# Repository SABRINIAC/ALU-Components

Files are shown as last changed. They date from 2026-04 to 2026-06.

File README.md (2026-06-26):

# ALU Modules

| What it is

This project is the collection of PCB that make up all of the Intel 8080 (Which is what my CPU is based on) ALU's functionality. \
It contains modules for an 8 bit adder, subtractor, AND, OR, XOR, rotate left, and rotate right. Also it has a NOT module for the CMA instruction, which inverts all the bits in the accumulator register. \
Also coincidentally there are 8 modules, which will make multiplexing to choose data lines really nice and easy! If I ever decide to create the module for DAA, which I don't have atm because im kinda lazy and I think it'll be seldom used, I can alway make the NOT module not on the multiplex because it is exclusively used to invert the accumulator register for CMA and nothing else.

| Why I made it

Most of my reasoning can be found in the [RAM Module readme](https://github.com/SABRINIAC/DelayLineRAM-ShiftRegister) but aside from that I made this so I can do what CPUs are really good for. Math! These modules alone, making up the ALU, accounts for 96 out of the 255 instructions my CPU needs. Over a third at 37.6%! \
I don't think another project will get even close to implementing that many instructions! They would need a combination of making registers, and routing on the motherboard; which tbf the ALU also needs that. \

Also, making a computer out of pure transistors sounds really cool! Getting to learn how to make logic gates with them was fun, but I don't think I've fully committed how they precisely work to my brain yet... maybe later on in this project.

| Pictures

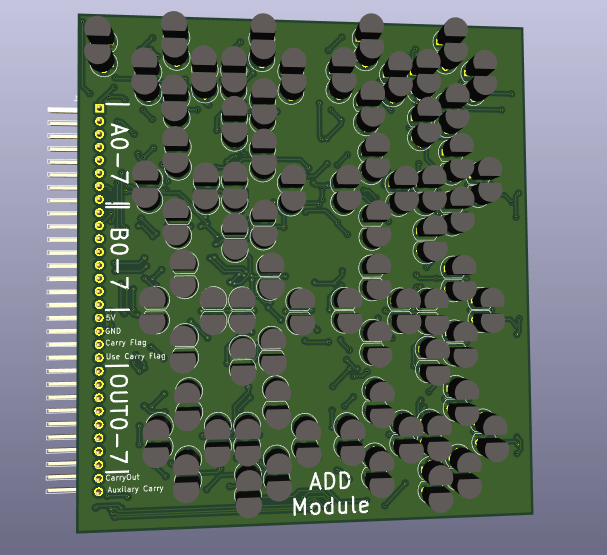
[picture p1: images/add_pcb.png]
Adder


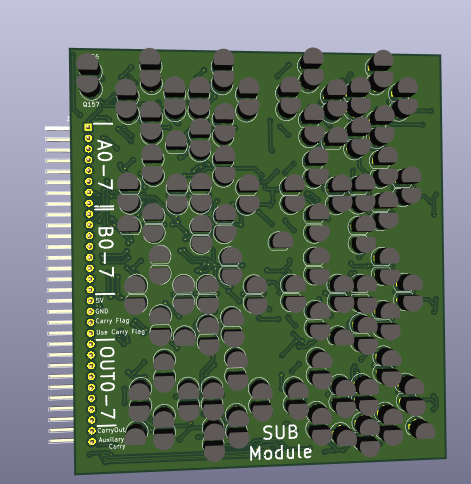
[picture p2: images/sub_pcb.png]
Subtractor


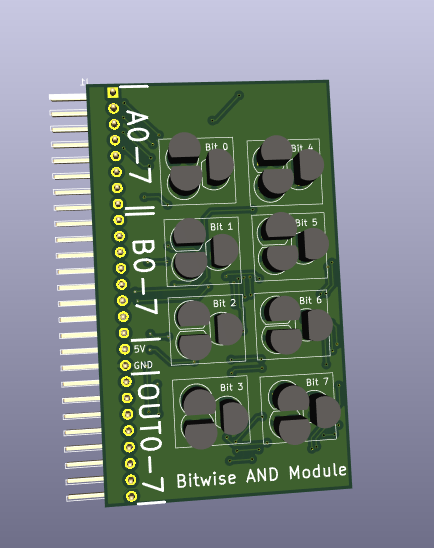
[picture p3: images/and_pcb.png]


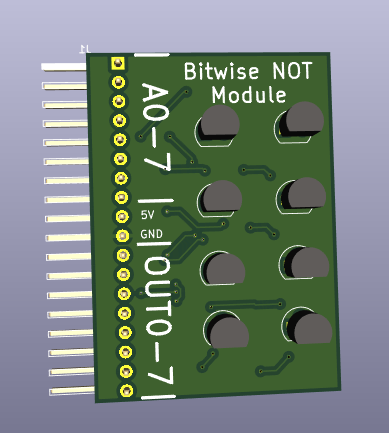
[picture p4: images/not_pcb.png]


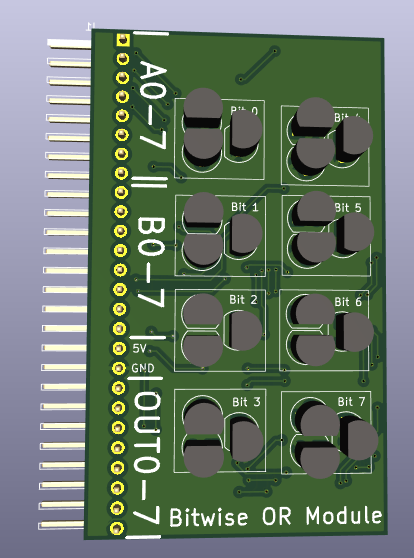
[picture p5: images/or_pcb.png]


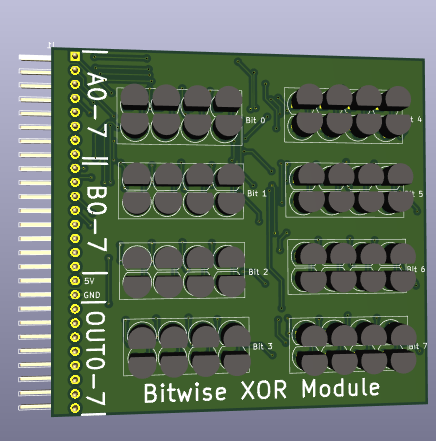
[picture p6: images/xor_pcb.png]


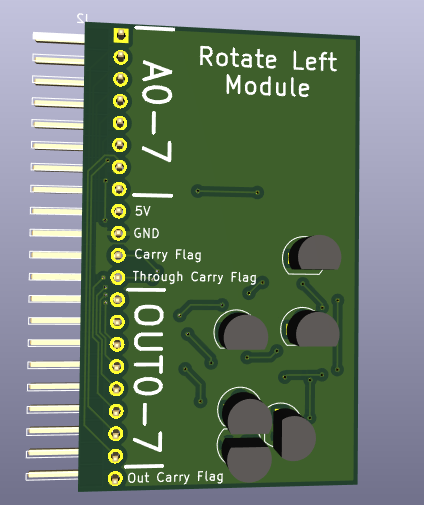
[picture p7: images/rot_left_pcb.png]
Rot. Left


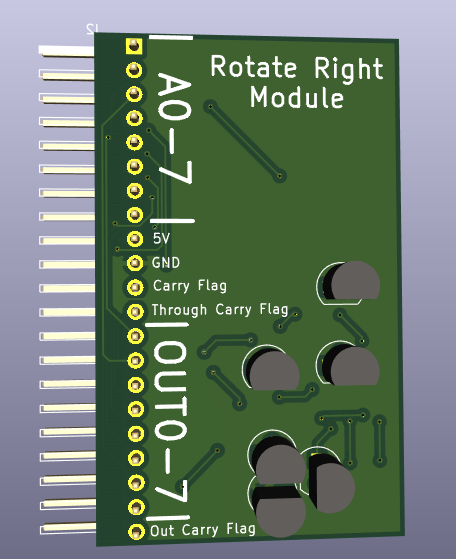
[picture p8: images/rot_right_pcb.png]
Rot. Right


| BOM + Quantity

You can see a greater breakdown in BOM.md, but here the table breakdown
| Part Name | Count |
|---|---|
| 1x2 Male Pin Headers | 99 |
| 2N2222 NPN Transistors | 432 |
| 1kΩ Resistor 0603 SMD | 670 |
| Adder PCB | 1 |
| Subtractor PCB | 1 |
| AND PCB | 1 |
| XOR PCB | 1 |
| OR PCB | 1 |
| NOT PCB | 1 |
| Rotate Right PCB | 1 |
| Rotate Left PCB | 1 |

# Built Modules
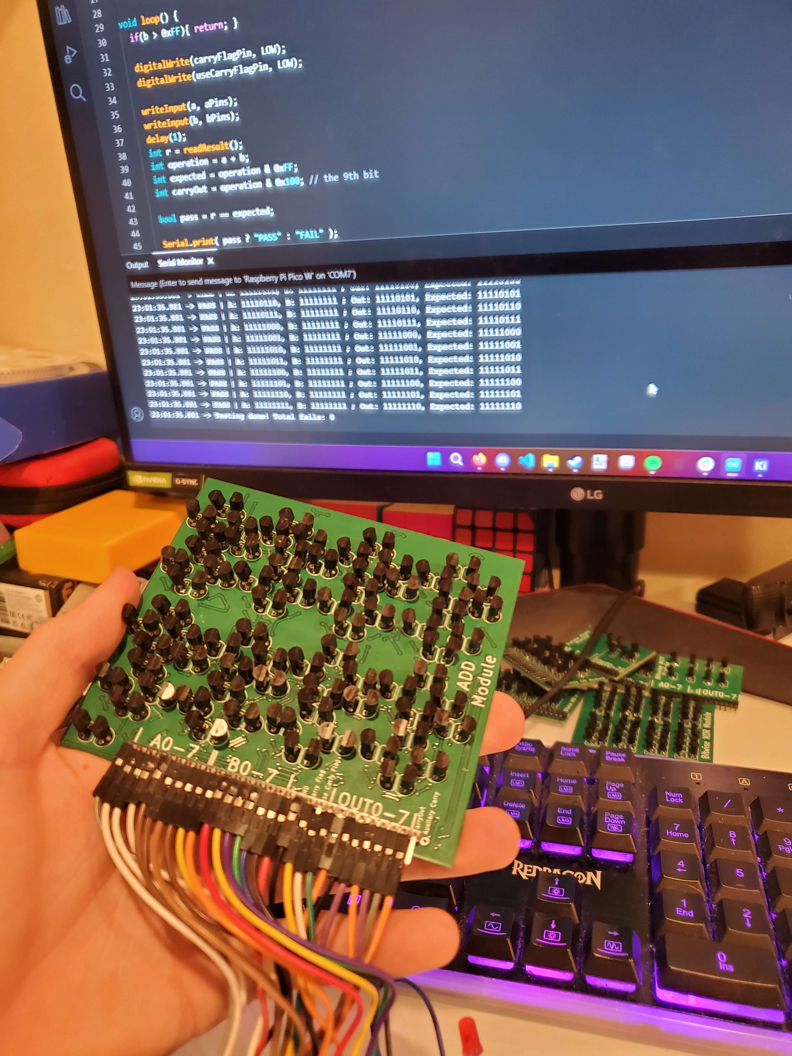
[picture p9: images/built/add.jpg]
Add

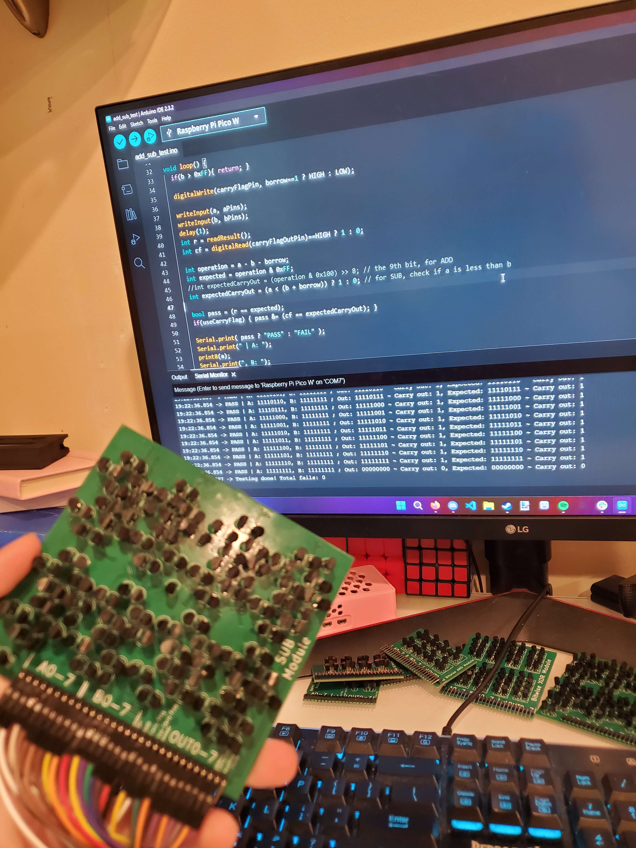
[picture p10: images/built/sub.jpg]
Sub

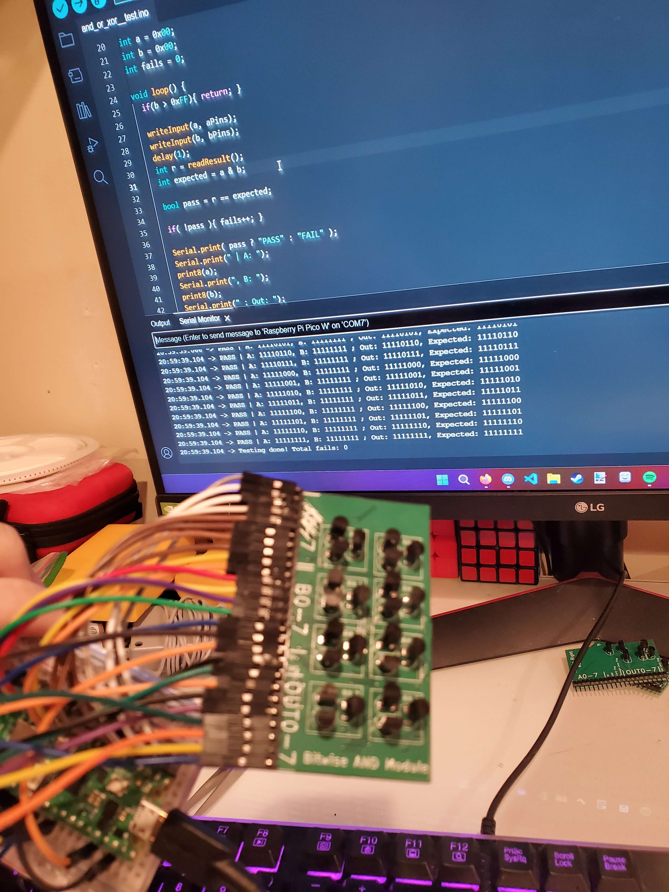
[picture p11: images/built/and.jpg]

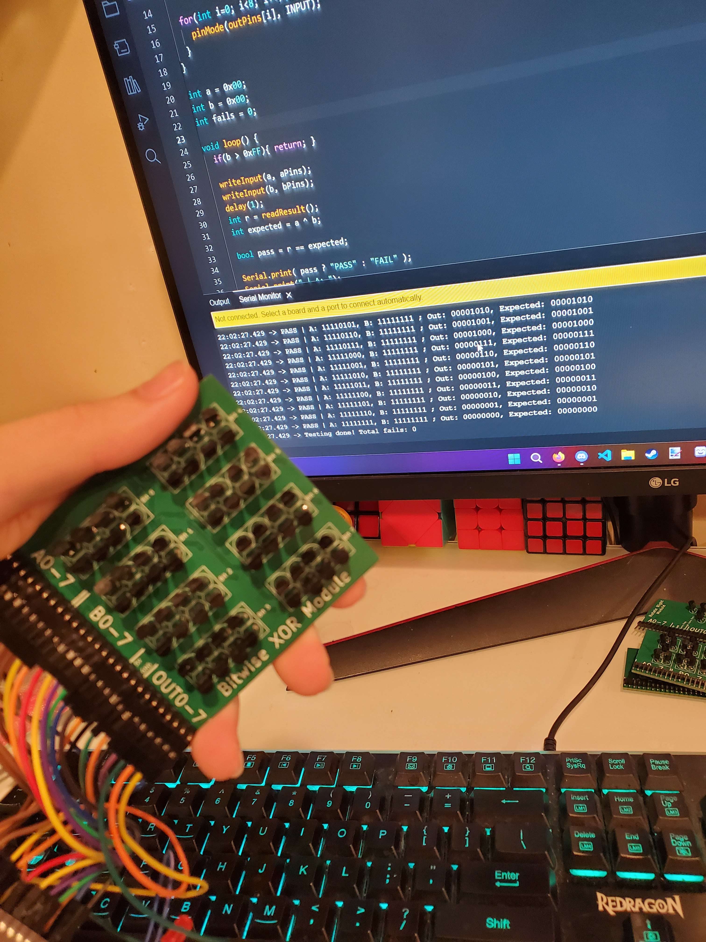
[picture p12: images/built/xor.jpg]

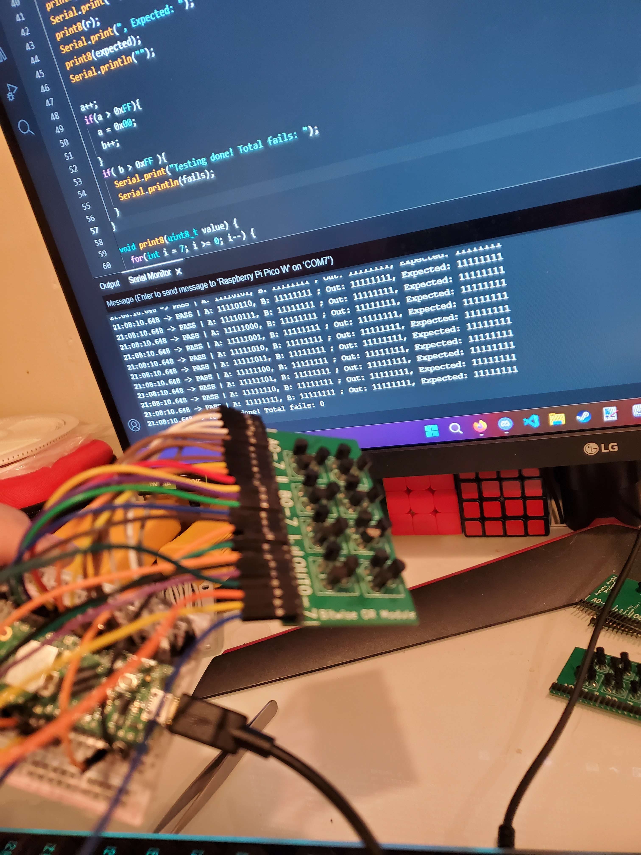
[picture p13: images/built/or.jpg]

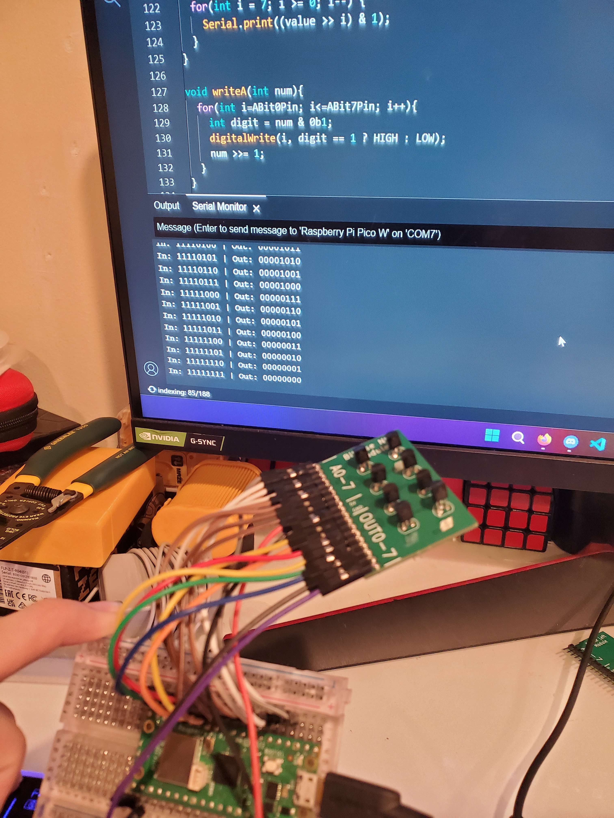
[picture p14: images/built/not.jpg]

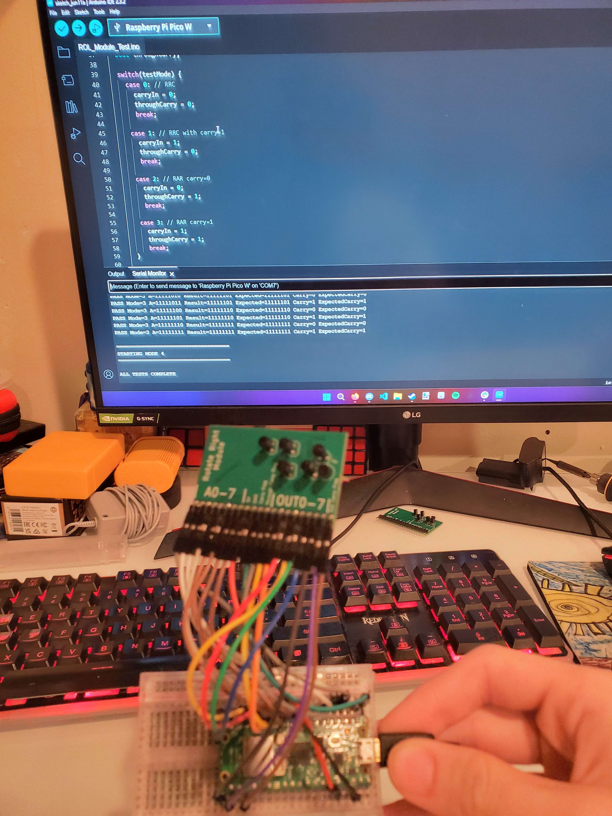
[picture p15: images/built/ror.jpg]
ROR

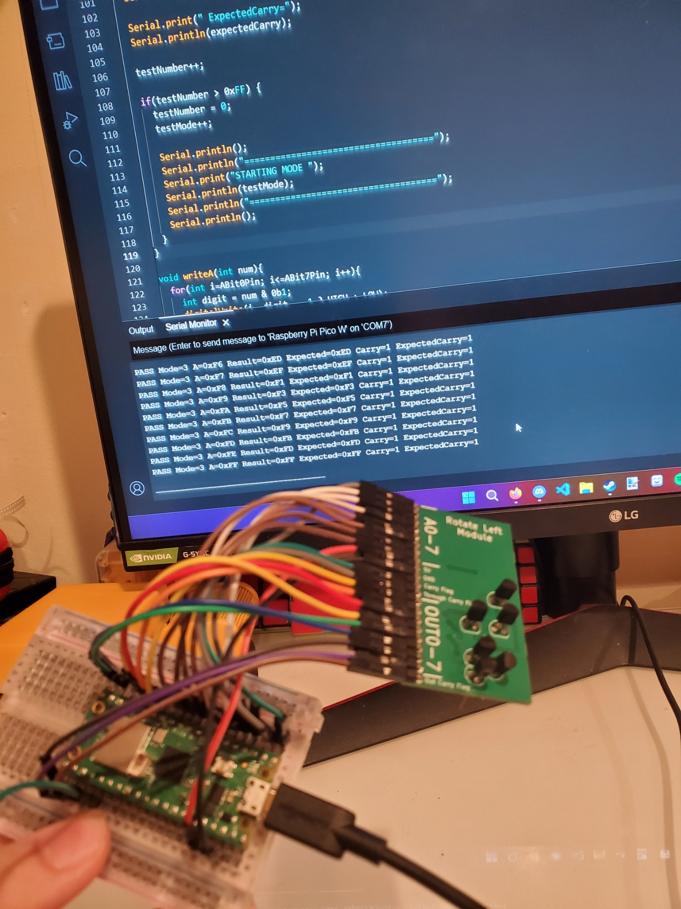
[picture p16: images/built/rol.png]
ROL


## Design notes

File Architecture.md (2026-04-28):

| What operations there are and their function
[Instruction Descriptions On Wikipedia](https://en.wikipedia.org/wiki/Intel_8080#Instruction_set) \

INR: Increment Register \
DCR: Decrement Register \
RLC: Accumulator << 1 ; Both the LSB and the Carry flag become old MSB \
RAL: Accumulator << 1 ; Carry flag becomes the old MSB ; LSB becomes the old Carry flag \
DAA: \
STC: Sets the carry flag to `1` | Don't include in the ALU? We can just modify the flag register? \
RRC: Accumulator >> 1 ; Both the MSB and Carry flag become the old LSB \
RAR: Accumulator >> 1 ; Carry flag becomes the old LSB ; MSB becomes the old carry flag \
CMA: Bitwise NOT on the current Accumulator ; Accumulator = !Accumulator \
CMC: Invert the carry flag | Don't include in the ALU? We can just modify the flag register? \
ADD + ADI: Add argument to the accumulator \
ADC + ACI: Add argument plus the carry flag to the accumulator \
SUB + SUI: Subtract the argument from the accumulator \
SBB + SBI: Subtract the argument and the carry flag from the accumulator \
ANA + ANI: Bitwise AND the argument with the accumulator \
XRA + XRI: Bitwise XOR the argument with the accumulator \
ORA + ORI: Bitwise OR the argument with the accumulator \
CMP + CPI: Accumulator minus the argument, but only changes flags \

| Circuits Needed

DAA: \
STC: Sets the carry flag to `1` | Don't include in the ALU? We can just modify the flag register? \
CMC: Invert the carry flag | Don't include in the ALU? We can just modify the flag register? \

~Adder; For INR, ADD, ADI, ADC, and ACI~ \
~Subtractor; For DCR, SUB, SUI, SBB, SBI, CMP, and CPI~ \
~Bitwise AND; For ANA, and ANI~ \
~Bitwise XOR; For XRA, and XRI~ \
~Bitwise OR; For ORA, and ORI~ \
~Bitwise NOT; For CMA~ \
~Rotate Right; For RRC, and RAR~ \
~Rotate Left; for RLC, and RAL~ \

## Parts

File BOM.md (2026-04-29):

Adder
- 1x Adder PCB
- 1x30 Male Pin Header
- 146 NPN Transistors
- 219 1kΩ Resistor 0603 SMD

Subtractor
- 1x Subtractor PCB
- 1x30 Male Pin Header
- 155 NPN Transistors
- 237 1kΩ Resistor 0603 SMD

Bitwise AND
- 1x AND PCB
- 1x26 Male Pin Header
- 23 NPN Transistors
- 40 1kΩ Resistor 0603 SMD

Bitwise XOR
- 1x XOR PCB
- 1x26 Male Pin Header
- 64 NPN Transistors
- 96 1kΩ Resistor 0603 SMD

Bitwise OR
- 1x OR PCB
- 1x26 Male Pin Header
- 24 NPN Transistors
- 40 1kΩ Resistor 0603 SMD

Bitwise NOT
- 1x NOT PCB
- 1x18 Male Pin Header
- 8 NPN Transistors
- 16 1kΩ Resistor 0603 SMD

Rotate Right
- 1x Rotate Right PCB
- 1x21 Male Pin Header
- 6 NPN Transistors
- 11 1kΩ Resistor 0603 SMD

Rotate Left
- 1x Rotate Left PCB
- 1x21 Male Pin Header
- 6 NPN Transistors
- 11 1kΩ Resistor 0603 SMD

**Total**:
- 99 1x2 Male Pin Header
- 432 NPN Transistors
- 670 1kΩ Resistor 0603 SMD
- 1x Adder PCB
- 1x Subtractor PCB
- 1x AND PCB
- 1x XOR PCB
- 1x OR PCB
- 1x NOT PCB
- 1x Rotate Right PCB
- 1x Rotate Left PCB

**PCBs** \
From JLCPCB
- $2 for the first PCB, then $4 per PCB after that -> $30
- Shipping: $3.30 fro the first, ~$1.30 to add 1 more PCB to that same shipment -> 3.30 + 7 * (1.30) = $12.4
- Or just $15.09 for shipping if I order them at the same time

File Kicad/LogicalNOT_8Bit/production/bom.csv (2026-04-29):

Designator | Footprint | Quantity | Value | LCSC Part #
J1 | PinHeader_1x18_P2.54mm_Horizontal | 1 | Conn_01x18_Pin
Q1, Q2, Q3, Q4, Q5, Q6, Q7, Q8 | TO-92 | 8 | NPN
R1, R10, R11, R12, R13, R14, R15, R16, R2, R3, R4, R5, R6, R7, R8, R9 | 0603 | 16 | 1kΩ

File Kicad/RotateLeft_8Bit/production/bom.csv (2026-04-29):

Designator | Footprint | Quantity | Value | LCSC Part #
J2 | PinHeader_1x21_P2.54mm_Horizontal | 1 | Conn_01x21_Pin
Q1, Q2, Q3, Q4, Q5, Q6 | TO-92 | 6 | NPN
R1, R10, R11, R2, R3, R4, R5, R6, R7, R8, R9 | 0603 | 11 | 1kΩ

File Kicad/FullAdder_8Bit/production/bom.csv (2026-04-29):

Designator | Footprint | Quantity | Value | LCSC Part #
J1 | PinHeader_1x30_P2.54mm_Horizontal | 1 | Conn_01x30_Pin
Q10, Q100, Q101, Q102, Q103, Q104, Q105, Q106, Q107, Q108, Q109, Q11, Q110, Q111, Q112, Q113, Q114, Q115, Q116, Q117, Q118, Q119, Q12, Q120, Q121, Q122, Q123, Q124, Q125, Q126, Q127, Q128, Q129, Q13, Q130, Q131, Q132, Q133, Q134, Q135, Q136, Q137, Q138, Q139, Q14, Q140, Q141, Q142, Q143, Q144, Q145, Q146, Q147, Q148, Q15, Q16, Q17, Q18, Q19, Q20, Q21, Q22, Q23, Q24, Q25, Q26, Q27, Q28, Q29, Q3, Q30, Q31, Q32, Q33, Q34, Q35, Q36, Q37, Q38, Q39, Q4, Q40, Q41, Q42, Q43, Q44, Q45, Q46, Q47, Q48, Q49, Q5, Q50, Q51, Q52, Q53, Q54, Q55, Q56, Q57, Q58, Q59, Q6, Q60, Q61, Q62, Q63, Q64, Q65, Q66, Q67, Q68, Q69, Q7, Q70, Q71, Q72, Q73, Q74, Q75, Q76, Q77, Q78, Q79, Q8, Q80, Q81, Q82, Q83, Q84, Q85, Q86, Q87, Q88, Q89, Q9, Q90, Q91, Q92, Q93, Q94, Q95, Q96, Q97, Q98, Q99 | TO-92 | 146 | NPN
R10, R100, R101, R102, R103, R104, R105, R106, R107, R108, R109, R11, R110, R111, R112, R113, R114, R115, R116, R117, R118, R119, R12, R120, R121, R122, R123, R124, R125, R126, R127, R128, R129, R13, R130, R131, R132, R133, R134, R135, R136, R137, R138, R139, R14, R140, R141, R142, R143, R144, R145, R146, R147, R148, R149, R15, R150, R151, R152, R153, R154, R155, R156, R157, R158, R159, R16, R160, R161, R162, R163, R164, R165, R166, R167, R168, R169, R17, R170, R171, R172, R173, R174, R175, R176, R177, R178, R179, R18, R180, R181, R182, R183, R184, R185, R186, R187, R188, R189, R19, R190, R191, R192, R193, R194, R195, R196, R197, R198, R199, R20, R200, R201, R202, R203, R204, R205, R206, R207, R208, R209, R21, R210, R211, R212, R213, R214, R215, R216, R217, R218, R219, R22, R220, R221, R222, R23, R24, R25, R26, R27, R28, R29, R30, R31, R32, R33, R34, R35, R36, R37, R38, R39, R4, R40, R41, R42, R43, R44, R45, R46, R47, R48, R49, R5, R50, R51, R52, R53, R54, R55, R56, R57, R58, R59, R6, R60, R61, R62, R63, R64, R65, R66, R67, R68, R69, R7, R70, R71, R72, R73, R74, R75, R76, R77, R78, R79, R8, R80, R81 | 0603 | 200 | 1kΩ
R82, R83, R84, R85, R86, R87, R88, R89, R9, R90, R91, R92, R93, R94, R95, R96, R97, R98, R99 | 0603 | 19 | 1kΩ

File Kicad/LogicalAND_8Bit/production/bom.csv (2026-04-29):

Designator | Footprint | Quantity | Value | LCSC Part #
J1 | PinHeader_1x26_P2.54mm_Horizontal | 1 | Conn_01x26_Pin
Q1, Q10, Q11, Q12, Q13, Q14, Q15, Q16, Q17, Q18, Q19, Q2, Q20, Q21, Q22, Q23, Q24, Q3, Q4, Q5, Q6, Q7, Q8, Q9 | TO-92 | 24 | NPN
R1, R10, R11, R12, R13, R14, R15, R16, R17, R18, R19, R2, R20, R21, R22, R23, R24, R25, R26, R27, R28, R29, R3, R30, R31, R32, R33, R34, R35, R36, R37, R38, R39, R4, R40, R5, R6, R7, R8, R9 | 0603 | 40 | 1kΩ

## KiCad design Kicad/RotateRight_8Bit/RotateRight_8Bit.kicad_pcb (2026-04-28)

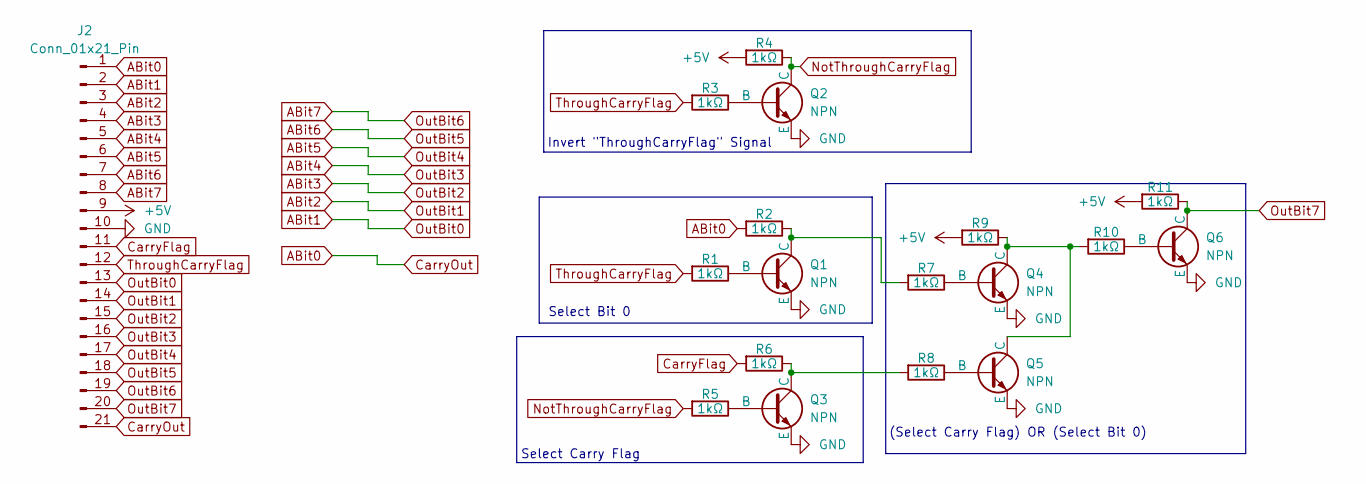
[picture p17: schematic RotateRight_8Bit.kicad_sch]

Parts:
J2: Conn_01x21_Pin; PinHeader_1x21_P2.54mm_Horizontal
Q1, Q2, Q3, Q4, Q5, Q6: NPN; TO-92
R1, R2, R3, R4, R5, R6, R7, R8, R9, R10, R11: 1kΩ; R_0603_1608Metric

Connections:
+5V: J2.9, R4.2, R9.2, R11.2
ABit0: J2.1, J2.21, R2.2
ABit1: J2.2, J2.13
ABit2: J2.3, J2.14
ABit3: J2.4, J2.15
ABit4: J2.5, J2.16
ABit5: J2.6, J2.17
ABit6: J2.7, J2.18
ABit7: J2.8, J2.19
CarryFlag: J2.11, R6.2
GND: J2.10, Q1.3 (E), Q2.3 (E), Q3.3 (E), Q4.3 (E), Q5.3 (E), Q6.3 (E)
unnamed: Q1.2 (B), R1.1
unnamed: Q1.1 (C), R2.1, R7.2
unnamed: Q2.2 (B), R3.1
unnamed: Q3.2 (B), R5.1
unnamed: Q3.1 (C), R6.1, R8.2
unnamed: Q4.2 (B), R7.1
unnamed: Q4.1 (C), Q5.1 (C), R9.1, R10.2
unnamed: Q5.2 (B), R8.1
unnamed: Q6.2 (B), R10.1
NotThroughCarryFlag: Q2.1 (C), R4.1, R5.2
OutBit7: J2.20, Q6.1 (C), R11.1
ThroughCarryFlag: J2.12, R1.2, R3.2

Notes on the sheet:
(Select Carry Flag) OR (Select Bit 0)
Select Bit 0
Select Carry Flag
Invert "ThroughCarryFlag" Signal

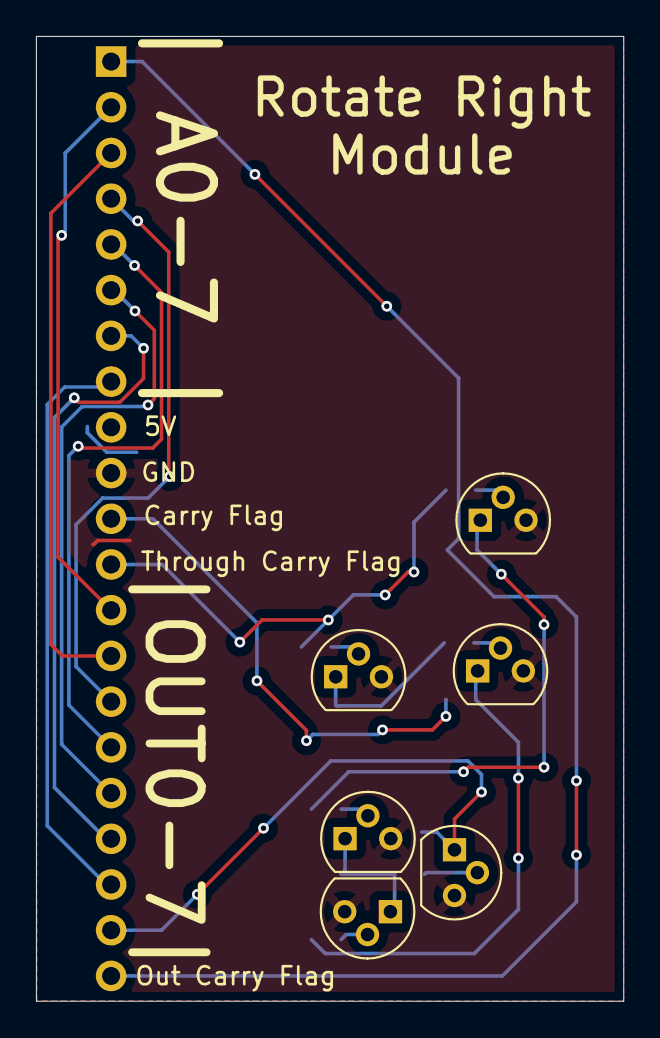
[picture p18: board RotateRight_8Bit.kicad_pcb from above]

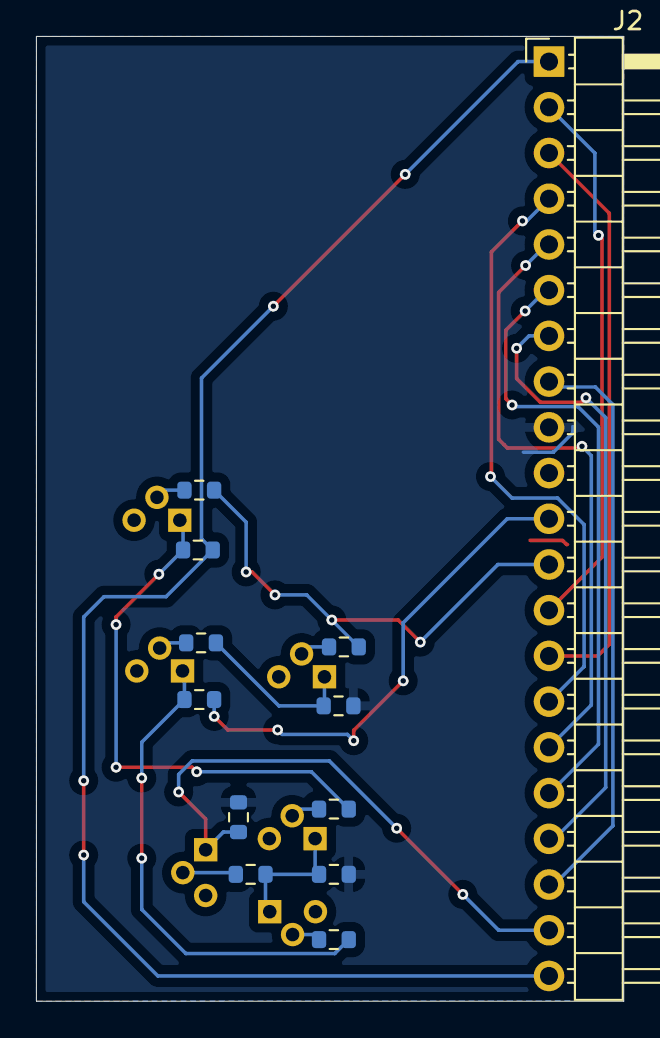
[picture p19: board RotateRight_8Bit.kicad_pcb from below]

Board: 2 copper layers, 32.6 x 53.6 mm, 18 parts (12 on the bottom side), 23 nets.

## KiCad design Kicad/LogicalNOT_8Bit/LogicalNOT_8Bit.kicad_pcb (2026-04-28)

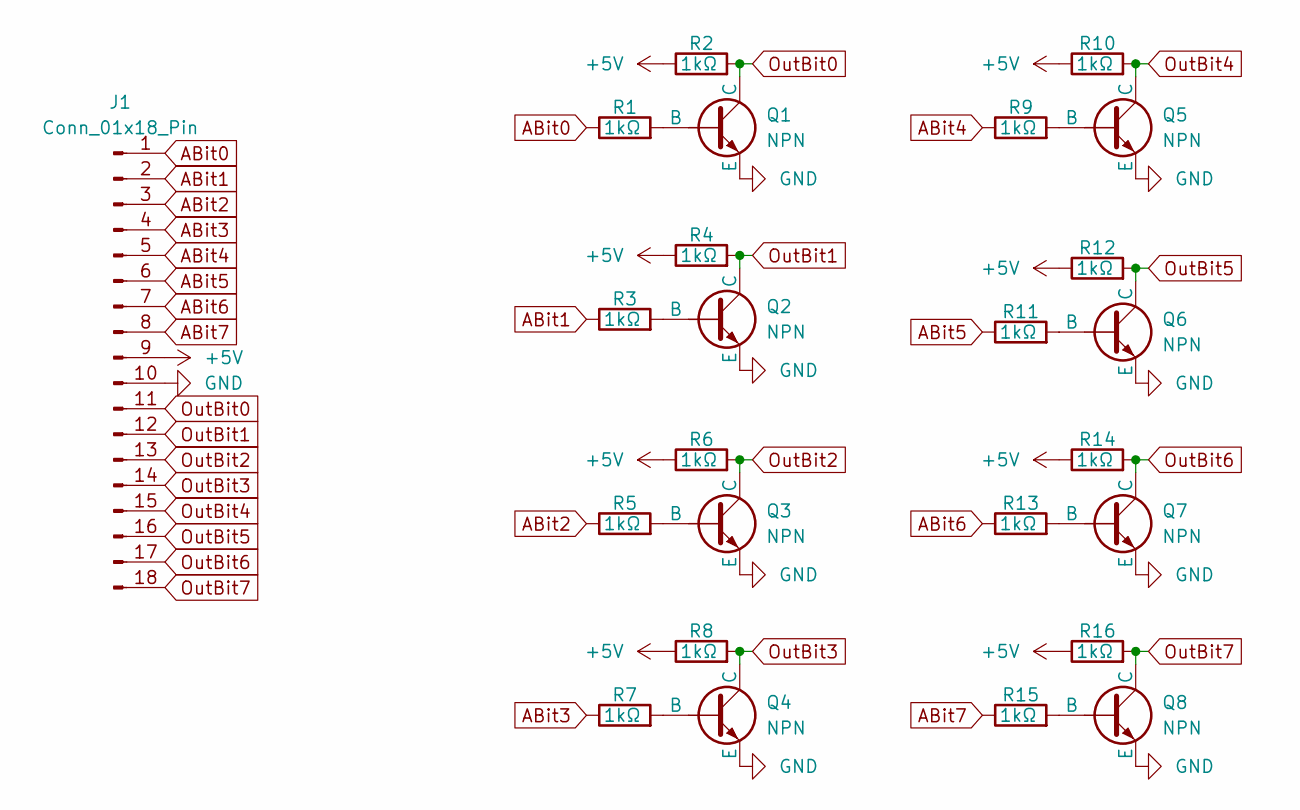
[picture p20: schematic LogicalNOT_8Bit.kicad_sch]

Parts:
J1: Conn_01x18_Pin; PinHeader_1x18_P2.54mm_Horizontal
Q1, Q2, Q3, Q4, Q5, Q6, Q7, Q8: NPN; TO-92
R1, R2, R3, R4, R5, R6, R7, R8, R9, R10, R11, R12, R13, R14, R15, R16: 1kΩ; R_0603_1608Metric

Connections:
+5V: J1.9, R2.1, R4.1, R6.1, R8.1, R10.1, R12.1, R14.1, R16.1
ABit0: J1.1, R1.1
ABit1: J1.2, R3.1
ABit2: J1.3, R5.1
ABit3: J1.4, R7.1
ABit4: J1.5, R9.1
ABit5: J1.6, R11.1
ABit6: J1.7, R13.1
ABit7: J1.8, R15.1
GND: J1.10, Q1.3 (E), Q2.3 (E), Q3.3 (E), Q4.3 (E), Q5.3 (E), Q6.3 (E), Q7.3 (E), Q8.3 (E)
unnamed: Q1.2 (B), R1.2
unnamed: Q2.2 (B), R3.2
unnamed: Q3.2 (B), R5.2
unnamed: Q4.2 (B), R7.2
unnamed: Q5.2 (B), R9.2
unnamed: Q6.2 (B), R11.2
unnamed: Q7.2 (B), R13.2
unnamed: Q8.2 (B), R15.2
OutBit0: J1.11, Q1.1 (C), R2.2
OutBit1: J1.12, Q2.1 (C), R4.2
OutBit2: J1.13, Q3.1 (C), R6.2
OutBit3: J1.14, Q4.1 (C), R8.2
OutBit4: J1.15, Q5.1 (C), R10.2
OutBit5: J1.16, Q6.1 (C), R12.2
OutBit6: J1.17, Q7.1 (C), R14.2
OutBit7: J1.18, Q8.1 (C), R16.2

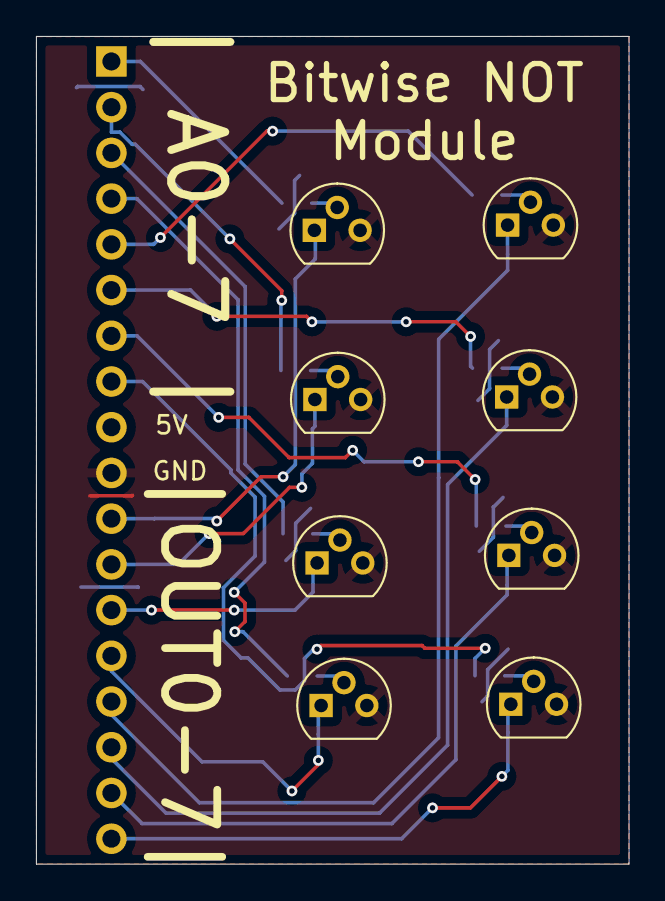
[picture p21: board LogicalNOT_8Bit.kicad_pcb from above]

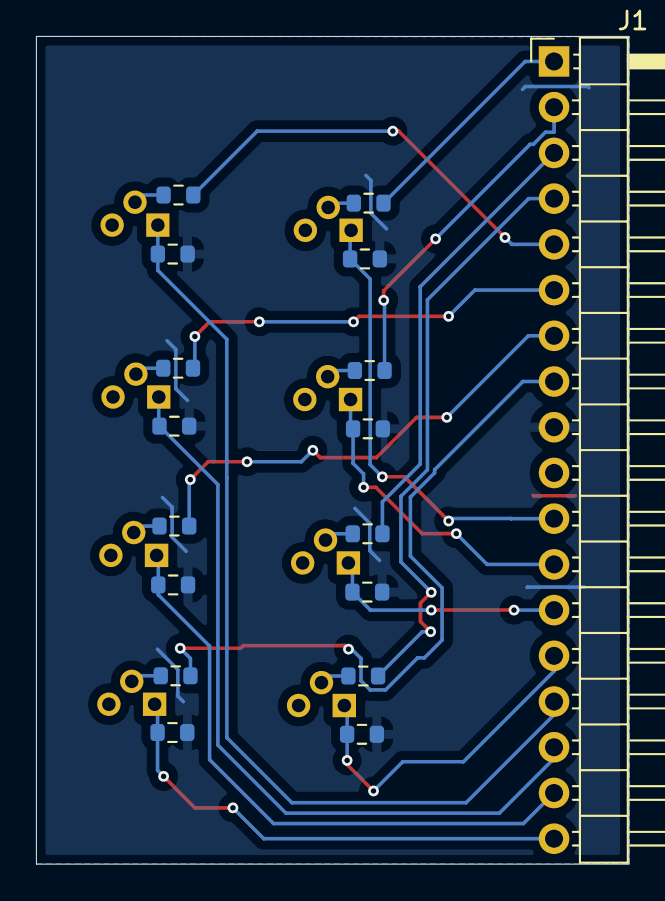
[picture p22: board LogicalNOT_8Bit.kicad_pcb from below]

Board: 2 copper layers, 32.9 x 46.0 mm, 25 parts (17 on the bottom side), 26 nets.

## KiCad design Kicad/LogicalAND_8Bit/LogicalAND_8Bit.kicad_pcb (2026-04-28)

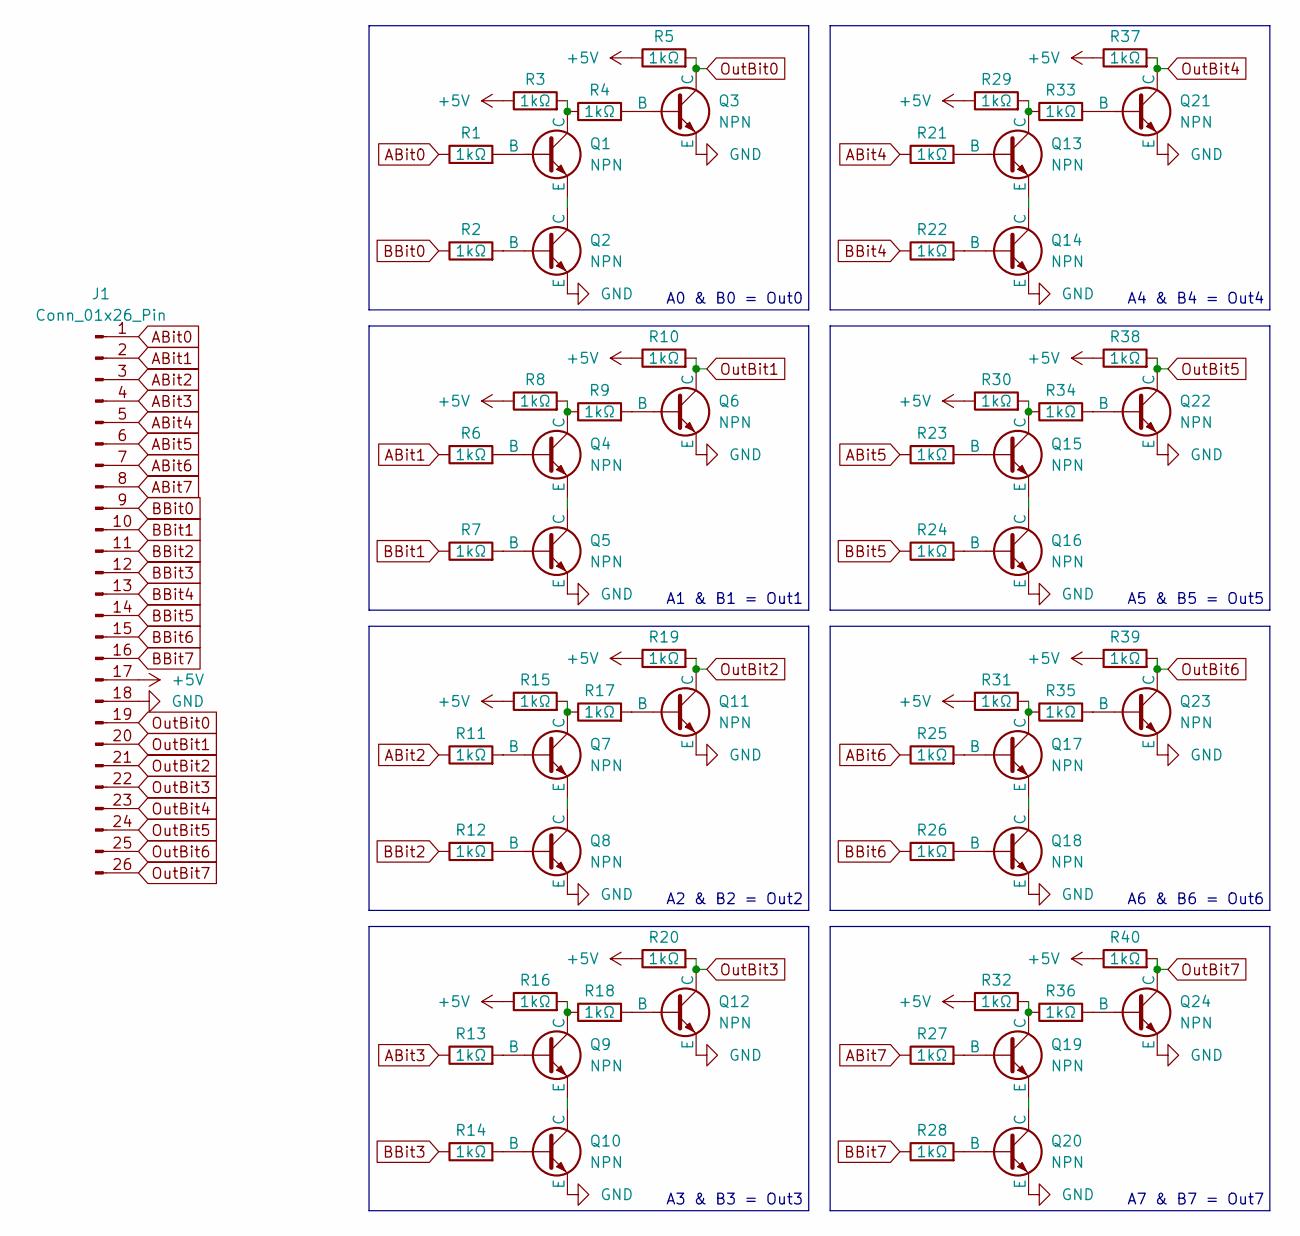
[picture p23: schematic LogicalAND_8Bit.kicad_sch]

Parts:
J1: Conn_01x26_Pin; PinHeader_1x26_P2.54mm_Horizontal
Q1, Q2, Q3, Q4, Q5, Q6, Q7, Q8, Q9, Q10, Q11, Q12, Q13, Q14, Q15, Q16, Q17, Q18, Q19, Q20, Q21, Q22, Q23, Q24: NPN; TO-92
R1, R2, R3, R4, R5, R6, R7, R8, R9, R10, R11, R12, R13, R14, R15, R16, R17, R18, R19, R20, R21, R22, R23, R24, R25, R26, R27, R28, R29, R30, R31, R32, R33, R34, R35, R36, R37, R38, R39, R40: 1kΩ; R_0603_1608Metric

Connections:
+5V: J1.17, R3.1, R5.1, R8.1, R10.1, R15.1, R16.1, R19.1, R20.1, R29.1, R30.1, R31.1, R32.1, R37.1, R38.1, R39.1, R40.1
ABit0: J1.1, R1.1
ABit1: J1.2, R6.1
ABit2: J1.3, R11.1
ABit3: J1.4, R13.1
ABit4: J1.5, R21.1
ABit5: J1.6, R23.1
ABit6: J1.7, R25.1
ABit7: J1.8, R27.1
BBit0: J1.9, R2.1
BBit1: J1.10, R7.1
BBit2: J1.11, R12.1
BBit3: J1.12, R14.1
BBit4: J1.13, R22.1
BBit5: J1.14, R24.1
BBit6: J1.15, R26.1
BBit7: J1.16, R28.1
GND: J1.18, Q2.3 (E), Q3.3 (E), Q5.3 (E), Q6.3 (E), Q8.3 (E), Q10.3 (E), Q11.3 (E), Q12.3 (E), Q14.3 (E), Q16.3 (E), Q18.3 (E), Q20.3 (E), Q21.3 (E), Q22.3 (E), Q23.3 (E), Q24.3 (E)
unnamed: Q1.2 (B), R1.2
unnamed: Q1.1 (C), R3.2, R4.1
unnamed: Q1.3 (E), Q2.1 (C)
unnamed: Q2.2 (B), R2.2
unnamed: Q3.2 (B), R4.2
unnamed: Q4.2 (B), R6.2
unnamed: Q4.1 (C), R8.2, R9.1
unnamed: Q4.3 (E), Q5.1 (C)
unnamed: Q5.2 (B), R7.2
unnamed: Q6.2 (B), R9.2
unnamed: Q7.2 (B), R11.2
unnamed: Q7.1 (C), R15.2, R17.1
unnamed: Q7.3 (E), Q8.1 (C)
unnamed: Q8.2 (B), R12.2
unnamed: Q9.2 (B), R13.2
unnamed: Q9.1 (C), R16.2, R18.1
unnamed: Q10.2 (B), R14.2
unnamed: Q9.3 (E), Q10.1 (C)
unnamed: Q11.2 (B), R17.2
unnamed: Q12.2 (B), R18.2
unnamed: Q13.2 (B), R21.2
unnamed: Q13.1 (C), R29.2, R33.1
unnamed: Q13.3 (E), Q14.1 (C)
unnamed: Q14.2 (B), R22.2
unnamed: Q15.2 (B), R23.2
unnamed: Q15.1 (C), R30.2, R34.1
unnamed: Q15.3 (E), Q16.1 (C)
unnamed: Q16.2 (B), R24.2
unnamed: Q17.2 (B), R25.2
unnamed: Q17.1 (C), R31.2, R35.1
unnamed: Q17.3 (E), Q18.1 (C)
unnamed: Q18.2 (B), R26.2
unnamed: Q19.2 (B), R27.2
unnamed: Q19.1 (C), R32.2, R36.1
unnamed: Q19.3 (E), Q20.1 (C)
unnamed: Q20.2 (B), R28.2
unnamed: Q21.2 (B), R33.2
unnamed: Q22.2 (B), R34.2
unnamed: Q23.2 (B), R35.2
unnamed: Q24.2 (B), R36.2
OutBit0: J1.19, Q3.1 (C), R5.2
OutBit1: J1.20, Q6.1 (C), R10.2
OutBit2: J1.21, Q11.1 (C), R19.2
OutBit3: J1.22, Q12.1 (C), R20.2
OutBit4: J1.23, Q21.1 (C), R37.2
OutBit5: J1.24, Q22.1 (C), R38.2
OutBit6: J1.25, Q23.1 (C), R39.2
OutBit7: J1.26, Q24.1 (C), R40.2

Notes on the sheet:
A7 & B7 = Out7
A4 & B4 = Out4
A6 & B6 = Out6
A0 & B0 = Out0
A3 & B3 = Out3
A2 & B2 = Out2
A1 & B1 = Out1
A5 & B5 = Out5

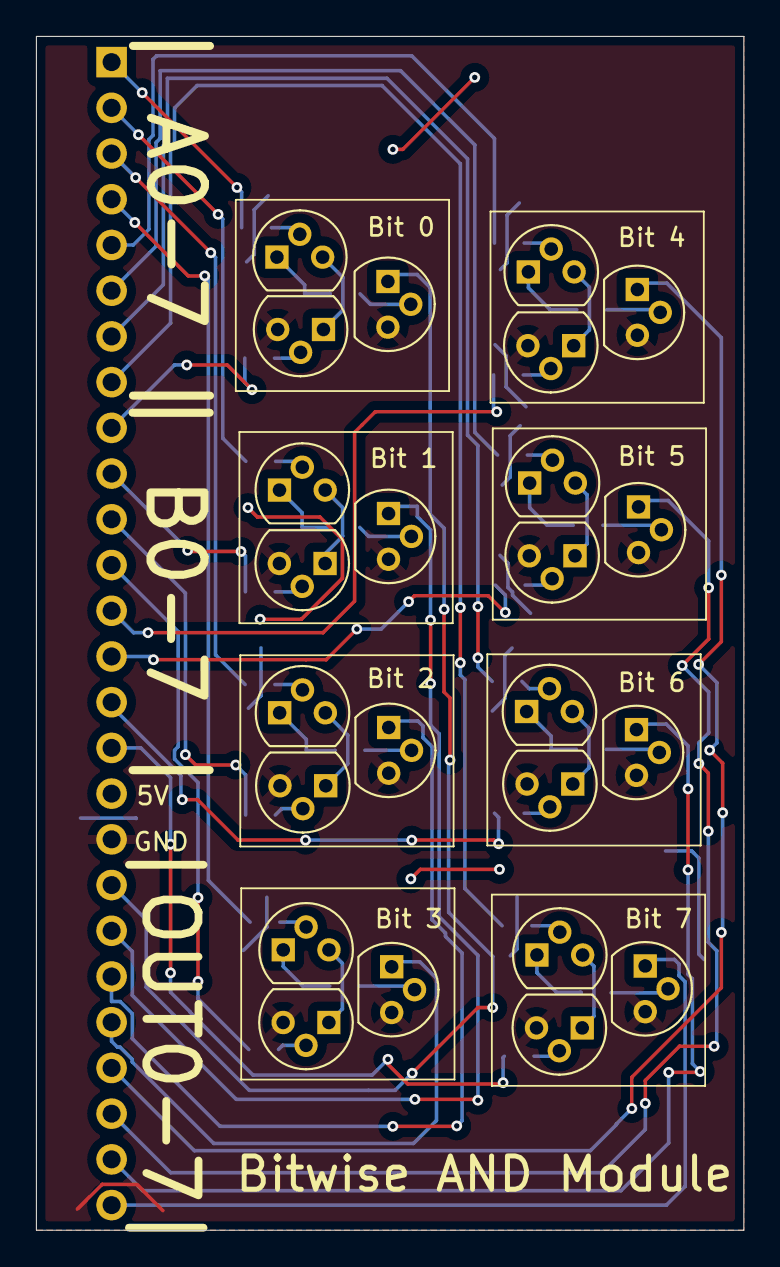
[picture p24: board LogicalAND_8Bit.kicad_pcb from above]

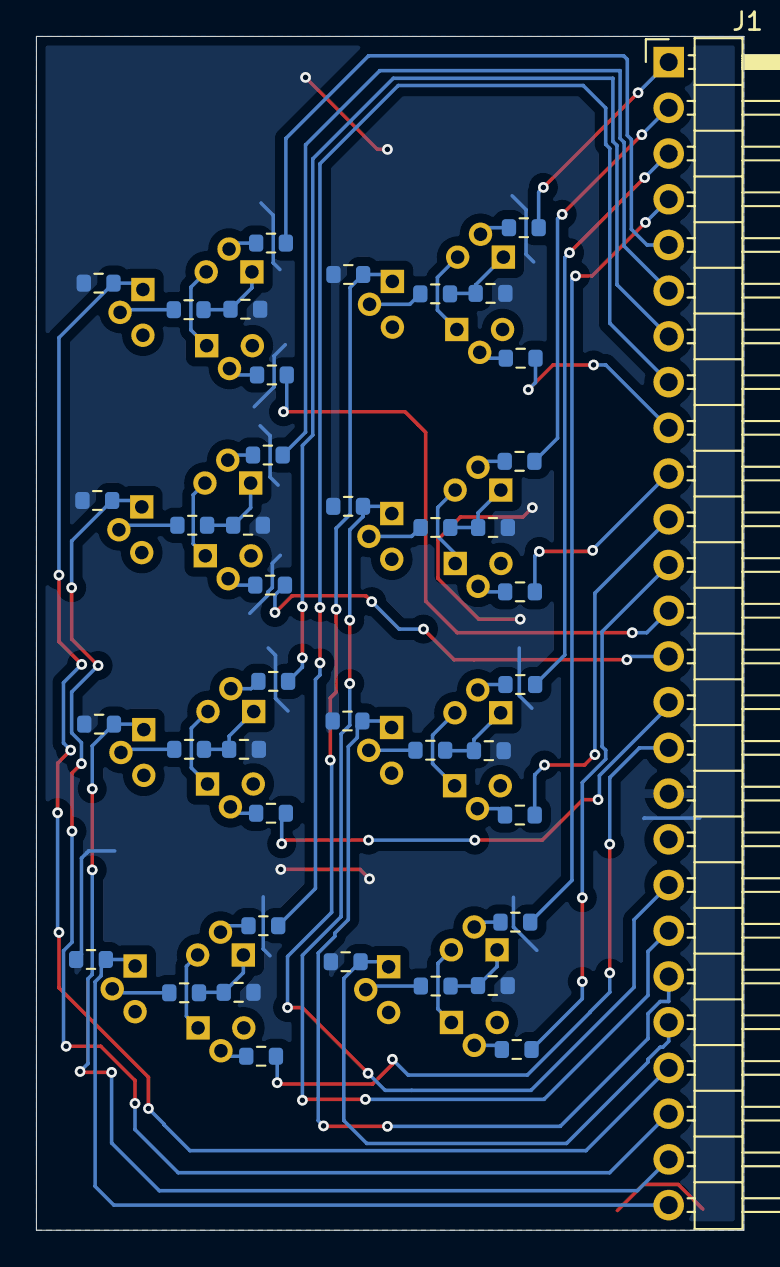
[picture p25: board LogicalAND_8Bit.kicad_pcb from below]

Board: 2 copper layers, 39.3 x 66.3 mm, 65 parts (41 on the bottom side), 66 nets.

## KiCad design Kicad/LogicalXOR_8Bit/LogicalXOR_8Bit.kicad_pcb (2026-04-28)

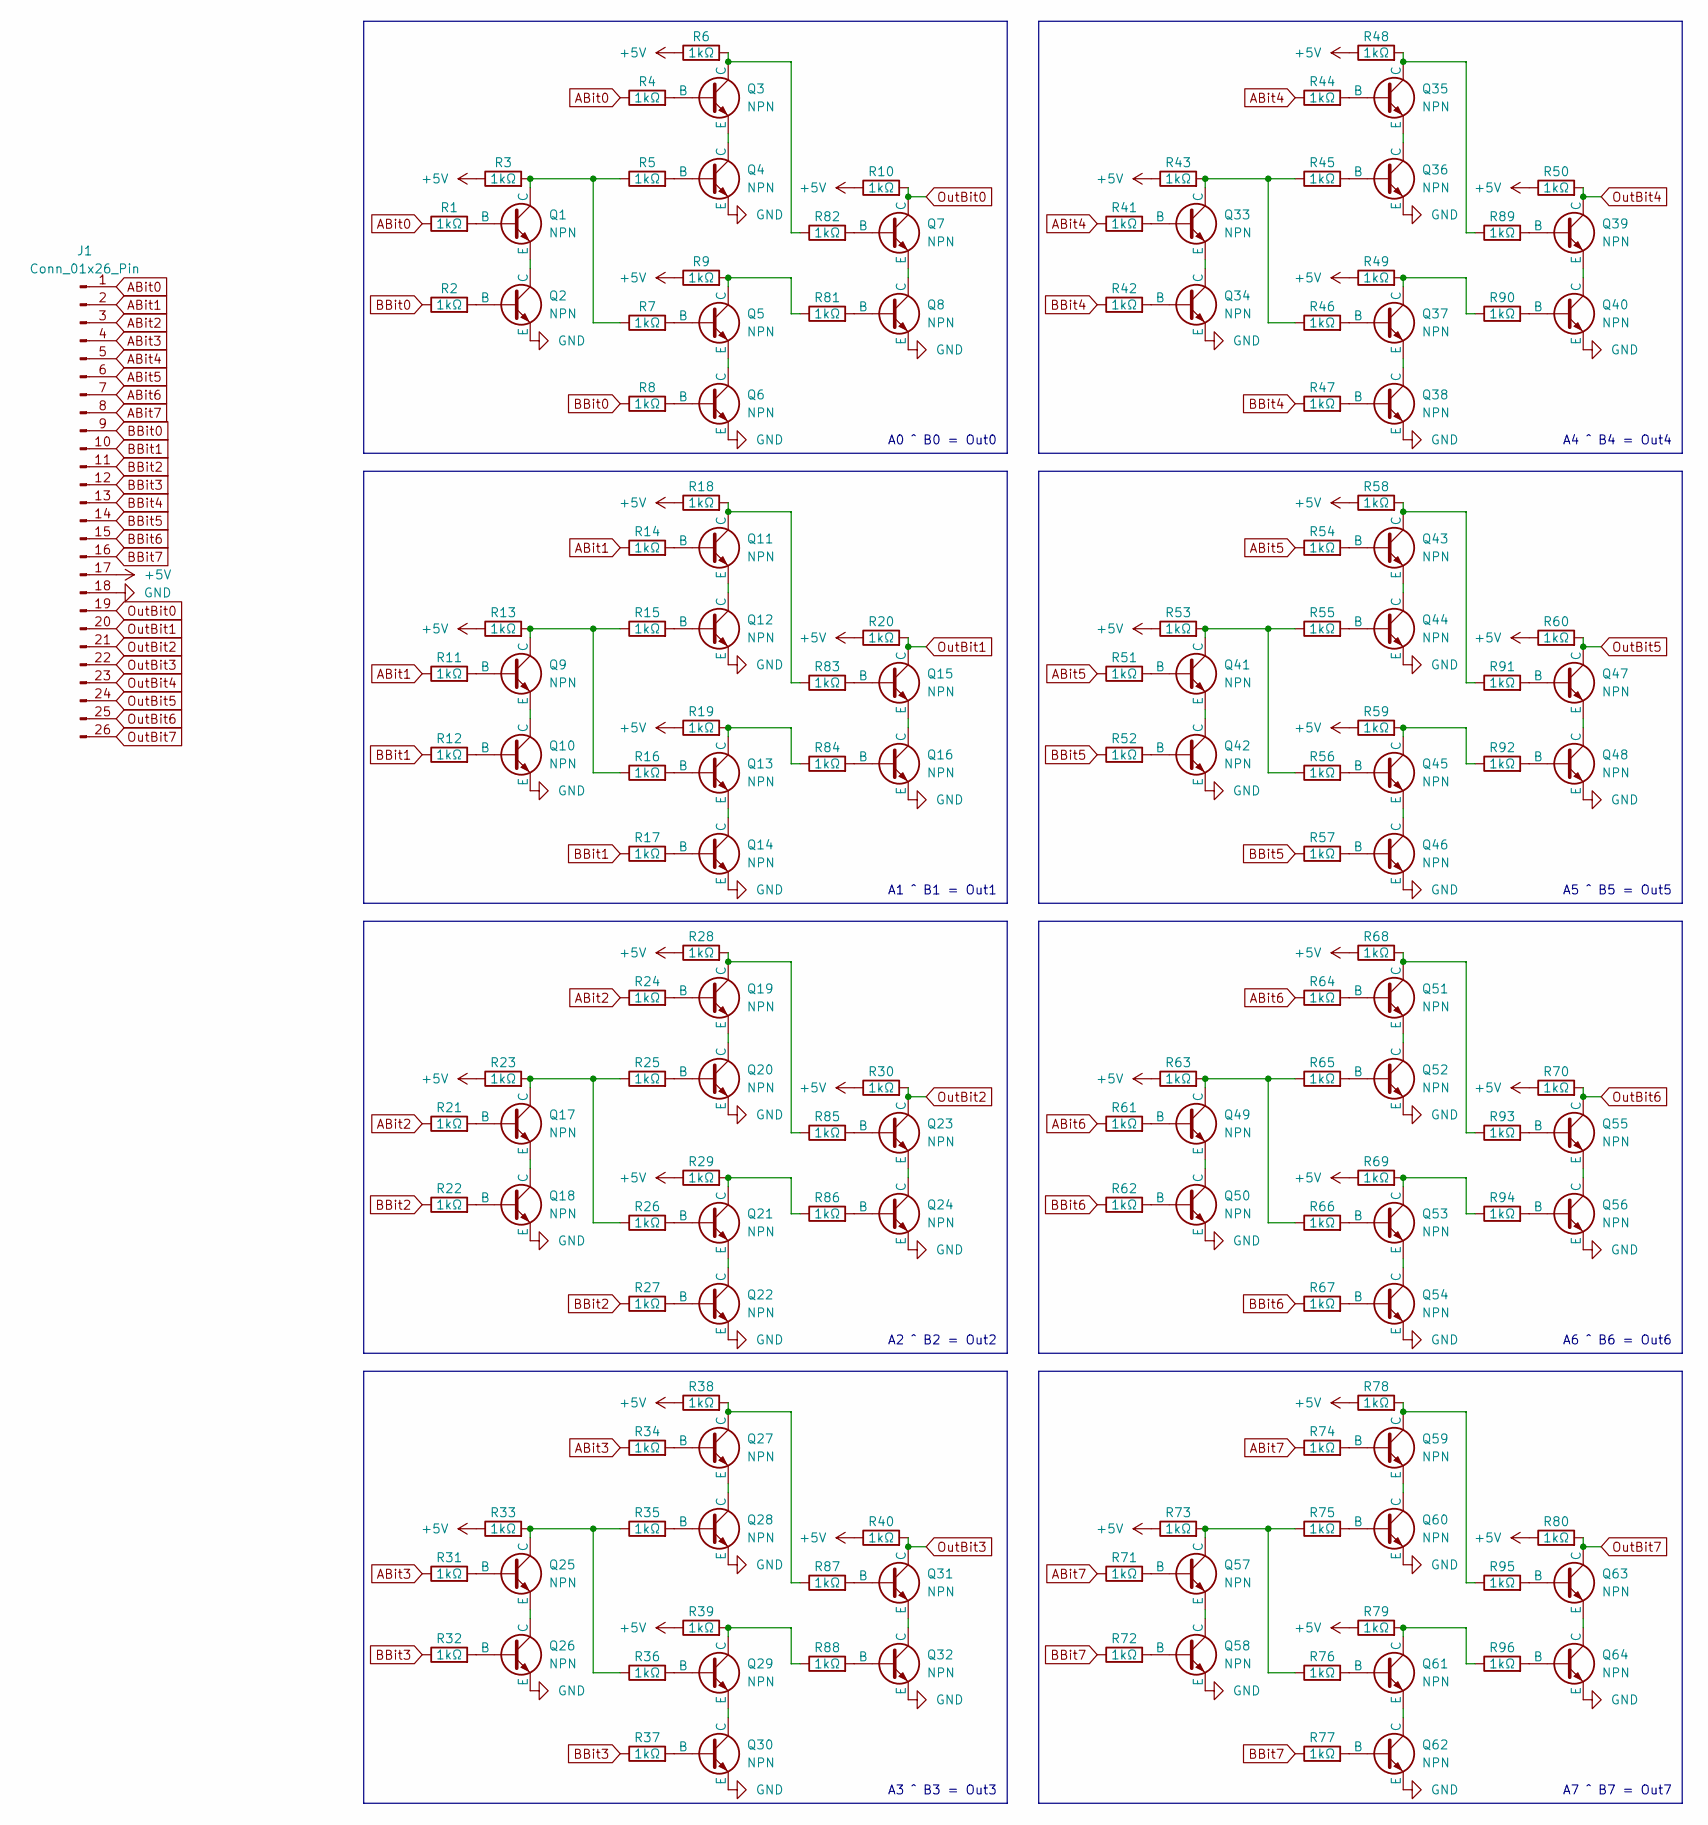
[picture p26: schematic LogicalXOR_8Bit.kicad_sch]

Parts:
J1: Conn_01x26_Pin; PinHeader_1x26_P2.54mm_Horizontal
Q1, Q2, Q3, Q4, Q5, Q6, Q7, Q8, Q9, Q10, Q11, Q12, Q13, Q14, Q15, Q16, Q17, Q18, Q19, Q20, Q21, Q22, Q23, Q24, Q25, Q26, Q27, Q28, Q29, Q30, Q31, Q32, Q33, Q34, Q35, Q36, Q37, Q38, Q39, Q40, Q41, Q42, Q43, Q44, Q45, Q46, Q47, Q48, Q49, Q50, Q51, Q52, Q53, Q54, Q55, Q56, Q57, Q58, Q59, Q60, Q61, Q62, Q63, Q64: NPN; TO-92
R1, R2, R3, R4, R5, R6, R7, R8, R9, R10, R11, R12, R13, R14, R15, R16, R17, R18, R19, R20, R21, R22, R23, R24, R25, R26, R27, R28, R29, R30, R31, R32, R33, R34, R35, R36, R37, R38, R39, R40, R41, R42, R43, R44, R45, R46, R47, R48, R49, R50, R51, R52, R53, R54, R55, R56, R57, R58, R59, R60, R61, R62, R63, R64, R65, R66, R67, R68, R69, R70, R71, R72, R73, R74, R75, R76, R77, R78, R79, R80, R81, R82, R83, R84, R85, R86, R87, R88, R89, R90, R91, R92, R93, R94, R95, R96: 1kΩ; R_0603_1608Metric

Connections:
+5V: J1.17, R3.1, R6.1, R9.1, R10.1, R13.1, R18.1, R19.1, R20.1, R23.1, R28.1, R29.1, R30.1, R33.1, R38.1, R39.1, R40.1, R43.1, R48.1, R49.1, R50.1, R53.1, R58.1, R59.1, R60.1, R63.1, R68.1, R69.1, R70.1, R73.1, R78.1, R79.1, R80.1
ABit0: J1.1, R1.1, R4.1
ABit1: J1.2, R11.1, R14.1
ABit2: J1.3, R21.1, R24.1
ABit3: J1.4, R31.1, R34.1
ABit4: J1.5, R41.1, R44.1
ABit5: J1.6, R51.1, R54.1
ABit6: J1.7, R61.1, R64.1
ABit7: J1.8, R71.1, R74.1
BBit0: J1.9, R2.1, R8.1
BBit1: J1.10, R12.1, R17.1
BBit2: J1.11, R22.1, R27.1
BBit3: J1.12, R32.1, R37.1
BBit4: J1.13, R42.1, R47.1
BBit5: J1.14, R52.1, R57.1
BBit6: J1.15, R62.1, R67.1
BBit7: J1.16, R72.1, R77.1
GND: J1.18, Q2.3 (E), Q4.3 (E), Q6.3 (E), Q8.3 (E), Q10.3 (E), Q12.3 (E), Q14.3 (E), Q16.3 (E), Q18.3 (E), Q20.3 (E), Q22.3 (E), Q24.3 (E), Q26.3 (E), Q28.3 (E), Q30.3 (E), Q32.3 (E), Q34.3 (E), Q36.3 (E), Q38.3 (E), Q40.3 (E), Q42.3 (E), Q44.3 (E), Q46.3 (E), Q48.3 (E), Q50.3 (E), Q52.3 (E), Q54.3 (E), Q56.3 (E), Q58.3 (E), Q60.3 (E), Q62.3 (E), Q64.3 (E)
unnamed: Q1.2 (B), R1.2
unnamed: Q1.1 (C), R3.2, R5.1, R7.1
unnamed: Q1.3 (E), Q2.1 (C)
unnamed: Q2.2 (B), R2.2
unnamed: Q3.2 (B), R4.2
unnamed: Q3.1 (C), R6.2, R82.1
unnamed: Q3.3 (E), Q4.1 (C)
unnamed: Q4.2 (B), R5.2
unnamed: Q5.2 (B), R7.2
unnamed: Q5.1 (C), R9.2, R81.1
unnamed: Q5.3 (E), Q6.1 (C)
unnamed: Q6.2 (B), R8.2
unnamed: Q7.2 (B), R82.2
unnamed: Q7.3 (E), Q8.1 (C)
unnamed: Q8.2 (B), R81.2
unnamed: Q9.2 (B), R11.2
unnamed: Q9.1 (C), R13.2, R15.1, R16.1
unnamed: Q10.2 (B), R12.2
unnamed: Q9.3 (E), Q10.1 (C)
unnamed: Q11.2 (B), R14.2
unnamed: Q11.1 (C), R18.2, R83.1
unnamed: Q11.3 (E), Q12.1 (C)
unnamed: Q12.2 (B), R15.2
unnamed: Q13.2 (B), R16.2
unnamed: Q13.1 (C), R19.2, R84.1
unnamed: Q13.3 (E), Q14.1 (C)
unnamed: Q14.2 (B), R17.2
unnamed: Q15.2 (B), R83.2
unnamed: Q15.3 (E), Q16.1 (C)
unnamed: Q16.2 (B), R84.2
unnamed: Q17.2 (B), R21.2
unnamed: Q17.1 (C), R23.2, R25.1, R26.1
unnamed: Q17.3 (E), Q18.1 (C)
unnamed: Q18.2 (B), R22.2
unnamed: Q19.2 (B), R24.2
unnamed: Q19.1 (C), R28.2, R85.1
unnamed: Q19.3 (E), Q20.1 (C)
unnamed: Q20.2 (B), R25.2
unnamed: Q21.2 (B), R26.2
unnamed: Q21.1 (C), R29.2, R86.1
unnamed: Q21.3 (E), Q22.1 (C)
unnamed: Q22.2 (B), R27.2
unnamed: Q23.2 (B), R85.2
unnamed: Q23.3 (E), Q24.1 (C)
unnamed: Q24.2 (B), R86.2
unnamed: Q25.2 (B), R31.2
unnamed: Q25.1 (C), R33.2, R35.1, R36.1
unnamed: Q25.3 (E), Q26.1 (C)
unnamed: Q26.2 (B), R32.2
unnamed: Q27.2 (B), R34.2
unnamed: Q27.1 (C), R38.2, R87.1
unnamed: Q27.3 (E), Q28.1 (C)
unnamed: Q28.2 (B), R35.2
unnamed: Q29.2 (B), R36.2
unnamed: Q29.1 (C), R39.2, R88.1
unnamed: Q29.3 (E), Q30.1 (C)
unnamed: Q30.2 (B), R37.2
unnamed: Q31.2 (B), R87.2
unnamed: Q31.3 (E), Q32.1 (C)
unnamed: Q32.2 (B), R88.2
unnamed: Q33.2 (B), R41.2
unnamed: Q33.1 (C), R43.2, R45.1, R46.1
unnamed: Q33.3 (E), Q34.1 (C)
unnamed: Q34.2 (B), R42.2
unnamed: Q35.2 (B), R44.2
unnamed: Q35.1 (C), R48.2, R89.1
unnamed: Q35.3 (E), Q36.1 (C)
unnamed: Q36.2 (B), R45.2
unnamed: Q37.2 (B), R46.2
unnamed: Q37.1 (C), R49.2, R90.1
unnamed: Q37.3 (E), Q38.1 (C)
unnamed: Q38.2 (B), R47.2
unnamed: Q39.2 (B), R89.2
unnamed: Q39.3 (E), Q40.1 (C)
unnamed: Q40.2 (B), R90.2
unnamed: Q41.2 (B), R51.2
unnamed: Q41.1 (C), R53.2, R55.1, R56.1
unnamed: Q41.3 (E), Q42.1 (C)
unnamed: Q42.2 (B), R52.2
unnamed: Q43.2 (B), R54.2
unnamed: Q43.1 (C), R58.2, R91.1
unnamed: Q43.3 (E), Q44.1 (C)
unnamed: Q44.2 (B), R55.2
unnamed: Q45.2 (B), R56.2
unnamed: Q45.1 (C), R59.2, R92.1
unnamed: Q45.3 (E), Q46.1 (C)
unnamed: Q46.2 (B), R57.2
unnamed: Q47.2 (B), R91.2
unnamed: Q47.3 (E), Q48.1 (C)
unnamed: Q48.2 (B), R92.2
unnamed: Q49.2 (B), R61.2
unnamed: Q49.1 (C), R63.2, R65.1, R66.1
unnamed: Q49.3 (E), Q50.1 (C)
unnamed: Q50.2 (B), R62.2
unnamed: Q51.2 (B), R64.2
unnamed: Q51.1 (C), R68.2, R93.1
unnamed: Q51.3 (E), Q52.1 (C)
unnamed: Q52.2 (B), R65.2
unnamed: Q53.2 (B), R66.2
unnamed: Q53.1 (C), R69.2, R94.1
unnamed: Q53.3 (E), Q54.1 (C)
unnamed: Q54.2 (B), R67.2
unnamed: Q55.2 (B), R93.2
unnamed: Q55.3 (E), Q56.1 (C)
unnamed: Q56.2 (B), R94.2
unnamed: Q57.2 (B), R71.2
unnamed: Q57.1 (C), R73.2, R75.1, R76.1
unnamed: Q57.3 (E), Q58.1 (C)
unnamed: Q58.2 (B), R72.2
unnamed: Q59.2 (B), R74.2
unnamed: Q59.1 (C), R78.2, R95.1
unnamed: Q59.3 (E), Q60.1 (C)
unnamed: Q60.2 (B), R75.2
unnamed: Q61.2 (B), R76.2
unnamed: Q61.1 (C), R79.2, R96.1
unnamed: Q61.3 (E), Q62.1 (C)
unnamed: Q62.2 (B), R77.2
unnamed: Q63.2 (B), R95.2
unnamed: Q63.3 (E), Q64.1 (C)
unnamed: Q64.2 (B), R96.2
OutBit0: J1.19, Q7.1 (C), R10.2
OutBit1: J1.20, Q15.1 (C), R20.2
OutBit2: J1.21, Q23.1 (C), R30.2
OutBit3: J1.22, Q31.1 (C), R40.2
OutBit4: J1.23, Q39.1 (C), R50.2
OutBit5: J1.24, Q47.1 (C), R60.2
OutBit6: J1.25, Q55.1 (C), R70.2
OutBit7: J1.26, Q63.1 (C), R80.2

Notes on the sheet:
A6 ^ B6 = Out6
A7 ^ B7 = Out7
A4 ^ B4 = Out4
A5 ^ B5 = Out5
A1 ^ B1 = Out1
A3 ^ B3 = Out3
A2 ^ B2 = Out2
A0 ^ B0 = Out0

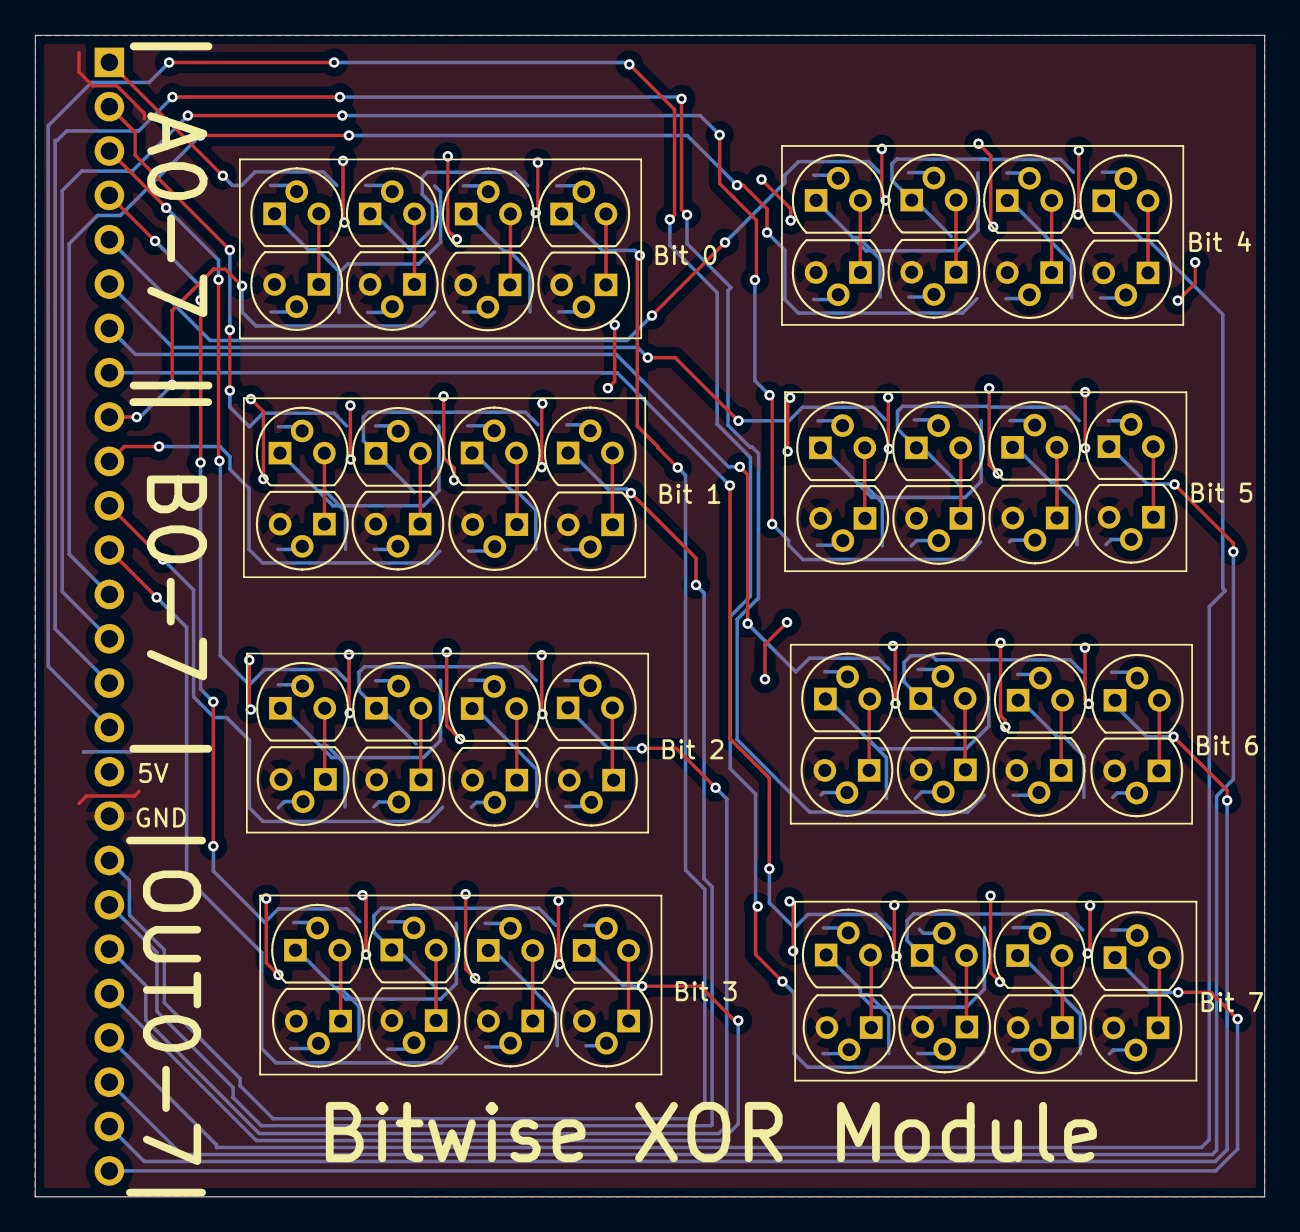
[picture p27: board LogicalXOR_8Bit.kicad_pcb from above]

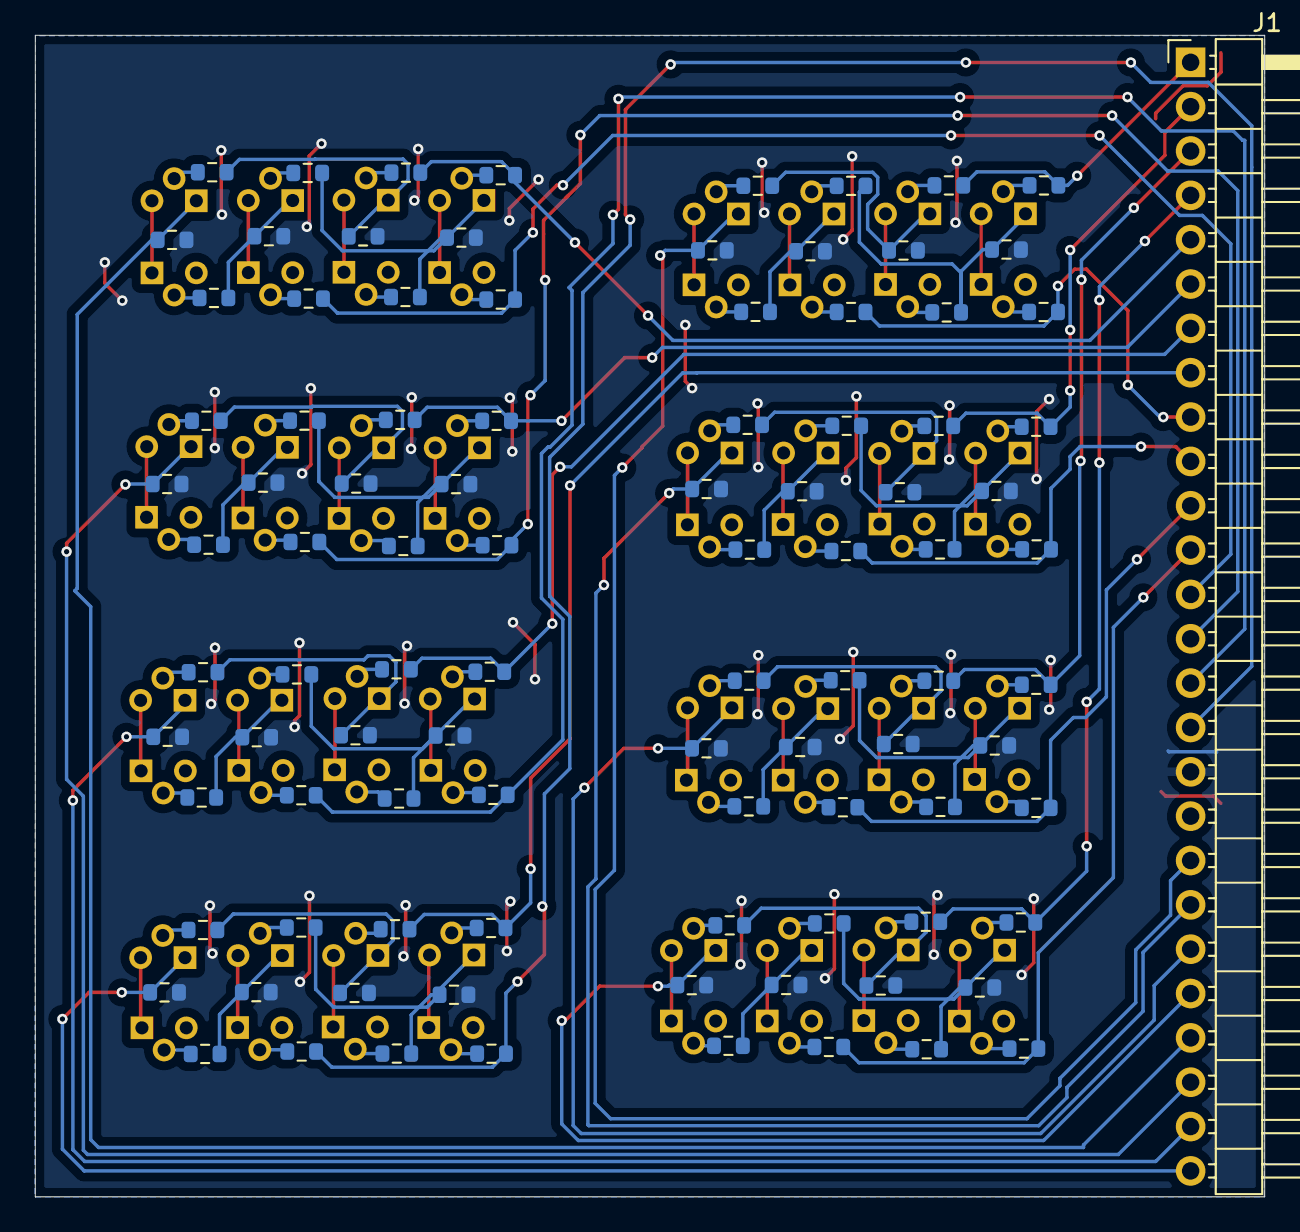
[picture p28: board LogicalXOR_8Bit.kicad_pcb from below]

Board: 2 copper layers, 70.4 x 66.5 mm, 161 parts (97 on the bottom side), 146 nets.

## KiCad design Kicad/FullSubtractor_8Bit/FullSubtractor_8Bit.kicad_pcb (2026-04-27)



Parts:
J1: Conn_01x30_Pin; PinHeader_1x30_P2.54mm_Horizontal
Q1, Q2, Q3, Q4, Q5, Q6, Q7, Q8, Q9, Q10, Q11, Q12, Q13, Q14, Q15, Q16, Q17, Q18, Q19, Q20, Q21, Q22, Q23, Q24, Q25, Q26, Q27, Q28, Q29, Q30, Q31, Q32, Q33, Q34, Q35, Q36, Q37, Q38, Q39, Q40, Q41, Q42, Q43, Q44, Q45, Q46, Q47, Q48, Q49, Q50, Q51, Q52, Q53, Q54, Q55, Q56, Q57, Q58, Q59, Q60, Q61, Q62, Q63, Q64, Q65, Q66, Q67, Q68, Q69, Q70, Q71, Q72, Q73, Q74, Q75, Q76, Q77, Q78, Q79, Q80, Q81, Q82, Q83, Q84, Q85, Q86, Q87, Q88, Q89, Q90, Q91, Q92, Q93, Q94, Q95, Q96, Q97, Q98, Q99, Q100, Q101, Q102, Q103, Q104, Q105, Q106, Q107, Q108, Q109, Q110, Q111, Q112, Q113, Q114, Q115, Q116, Q117, Q118, Q119, Q120, Q121, Q122, Q123, Q124, Q125, Q126, Q127, Q128, Q129, Q130, Q131, Q132, Q133, Q134, Q135, Q136, Q137, Q138, Q139, Q140, Q141, Q142, Q143, Q144, Q145, Q146, Q149, Q150, Q151, Q152, Q153, Q154, Q155, Q156, Q157: NPN; TO-92
R1, R2, R3, R4, R5, R6, R7, R8, R9, R10, R11, R12, R13, R14, R15, R16, R17, R18, R19, R20, R21, R22, R23, R24, R25, R26, R27, R28, R29, R30, R31, R32, R33, R34, R35, R36, R37, R38, R39, R40, R41, R42, R43, R44, R45, R46, R47, R48, R49, R50, R51, R52, R53, R54, R55, R56, R57, R58, R59, R60, R61, R62, R63, R64, R65, R66, R67, R68, R69, R70, R71, R72, R73, R74, R75, R76, R77, R78, R79, R80, R81, R82, R83, R84, R85, R86, R87, R88, R89, R90, R91, R92, R93, R94, R95, R96, R97, R98, R99, R100, R101, R102, R103, R104, R105, R106, R107, R108, R109, R110, R111, R112, R113, R114, R115, R116, R117, R118, R119, R120, R121, R122, R123, R124, R125, R126, R127, R128, R129, R130, R131, R132, R133, R134, R135, R136, R137, R138, R139, R140, R141, R142, R143, R144, R145, R146, R147, R148, R149, R150, R151, R152, R153, R154, R155, R156, R157, R158, R159, R160, R161, R162, R163, R164, R165, R166, R167, R168, R169, R170, R171, R172, R173, R174, R175, R176, R177, R178, R179, R180, R181, R182, R183, R184, R185, R186, R187, R188, R189, R190, R191, R192, R193, R194, R195, R196, R197, R198, R199, R200, R201, R202, R203, R204, R205, R206, R207, R208, R209, R210, R211, R212, R213, R214, R215, R216, R217, R218, R219, R223, R224, R225, R226, R227, R228, R229, R230, R231, R232, R233, R234, R235, R236, R237, R238, R239, R240: 1kΩ; R_0603_1608Metric

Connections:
+5V: J1.17, R2.1, R5.1, R8.1, R11.1, R14.1, R17.1, R20.1, R23.1, R26.1, R29.1, R32.1, R36.1, R37.1, R41.1, R44.1, R47.1, R51.1, R52.1, R56.1, R59.1, R63.1, R64.1, R68.1, R71.1, R74.1, R78.1, R79.1, R83.1, R86.1, R90.1, R91.1, R95.1, R98.1, R101.1, R105.1, R106.1, R110.1, R116.1, R117.1, R118.1, R119.1, R132.1, R133.1, R134.1, R135.1, R136.1, R137.1, R138.1, R139.1, R152.1, R153.1, R154.1, R155.1, R164.1, R165.1, R166.1, R167.1, R176.1, R177.1, R178.1, R179.1, R192.1, R193.1, R194.1, R195.1, R196.1, R197.1, R198.1, R199.1, R212.1, R213.1, R214.1, R215.1, R223.1, R225.1, R228.1, R229.1, R234.1, R235.1, R236.1, R237.1, R238.2
A_Bit0: J1.1, R4.1, R9.1
A_Bit1: J1.2, R31.1, R38.1
A_Bit2: J1.3, R58.1, R65.1
A_Bit3: J1.4, R85.1, R92.1
A_Bit4: J1.5, R112.1, R140.1
A_Bit5: J1.6, R113.1, R141.1
A_Bit6: J1.7, R114.1, R142.1
A_Bit7: J1.8, R115.1, R143.1
AuxiliaryCarry: J1.30, Q64.1 (C), Q66.1 (C), R98.2, R180.1, R204.1
B_Bit0: Q2.1 (C), R6.1, R12.1, R223.2
B_Bit0In: J1.9, R3.2
B_Bit1: Q149.1 (C), R33.1, R39.1, R225.2
B_Bit1In: J1.10, R224.2
B_Bit2: Q150.1 (C), R60.1, R66.1, R228.2
B_Bit2In: J1.11, R226.2
B_Bit3: Q151.1 (C), R87.1, R93.1, R229.2
B_Bit3In: J1.12, R227.2
B_Bit4: Q152.1 (C), R120.1, R144.1, R234.2
B_Bit4In: J1.13, R230.2
B_Bit5: Q153.1 (C), R121.1, R145.1, R235.2
B_Bit5In: J1.14, R231.2
B_Bit6: Q154.1 (C), R122.1, R146.1, R236.2
B_Bit6In: J1.15, R232.2
B_Bit7: Q155.1 (C), R123.1, R147.1, R237.2
B_Bit7In: J1.16, R233.2
Borrow0: Q19.1 (C), Q20.1 (C), R29.2, R48.1, R54.1
Borrow1: Q28.1 (C), Q30.1 (C), R44.2, R75.1, R81.1
Borrow2: Q46.1 (C), Q48.1 (C), R71.2, R102.1, R108.1
Borrow4: Q103.1 (C), Q111.1 (C), R164.2, R181.1, R205.1
Borrow5: Q104.1 (C), Q112.1 (C), R165.2, R182.1, R206.1
Borrow6: Q105.1 (C), Q113.1 (C), R166.2, R183.1, R207.1
Borrow7: Q106.1 (C), Q114.1 (C), R1.2, R167.2
BorrowOut: J1.29, Q1.1 (C), R2.2
Carry Flag: J1.19, R239.2
CarryIn_AdderBit0: Q156.1 (C), R18.1, R24.1, R238.1
GND: J1.18, Q1.3 (E), Q2.3 (E), Q3.3 (E), Q4.3 (E), Q5.3 (E), Q6.3 (E), Q7.3 (E), Q8.3 (E), Q9.3 (E), Q10.3 (E), Q11.3 (E), Q12.3 (E), Q13.3 (E), Q14.3 (E), Q15.3 (E), Q16.3 (E), Q17.3 (E), Q18.3 (E), Q19.3 (E), Q20.3 (E), Q21.3 (E), Q22.3 (E), Q23.3 (E), Q24.3 (E), Q25.3 (E), Q26.3 (E), Q27.3 (E), Q28.3 (E), Q29.3 (E), Q30.3 (E), Q31.3 (E), Q32.3 (E), Q33.3 (E), Q34.3 (E), Q35.3 (E), Q36.3 (E), Q37.3 (E), Q38.3 (E), Q39.3 (E), Q40.3 (E), Q41.3 (E), Q42.3 (E), Q43.3 (E), Q44.3 (E), Q45.3 (E), Q46.3 (E), Q47.3 (E), Q48.3 (E), Q49.3 (E), Q50.3 (E), Q51.3 (E), Q52.3 (E), Q53.3 (E), Q54.3 (E), Q55.3 (E), Q56.3 (E), Q57.3 (E), Q58.3 (E), Q59.3 (E), Q60.3 (E), Q61.3 (E), Q62.3 (E), Q63.3 (E), Q64.3 (E), Q65.3 (E), Q66.3 (E), Q67.3 (E), Q68.3 (E), Q69.3 (E), Q70.3 (E), Q71.3 (E), Q72.3 (E), Q73.3 (E), Q74.3 (E), Q75.3 (E), Q76.3 (E), Q77.3 (E), Q78.3 (E), Q79.3 (E), Q80.3 (E), Q81.3 (E), Q82.3 (E), Q83.3 (E), Q84.3 (E), Q85.3 (E), Q86.3 (E), Q87.3 (E), Q88.3 (E), Q89.3 (E), Q90.3 (E), Q91.3 (E), Q92.3 (E), Q93.3 (E), Q94.3 (E), Q95.3 (E), Q96.3 (E), Q97.3 (E), Q98.3 (E), Q99.3 (E), Q100.3 (E), Q101.3 (E), Q102.3 (E), Q103.3 (E), Q104.3 (E), Q105.3 (E), Q106.3 (E), Q107.3 (E), Q108.3 (E), Q109.3 (E), Q110.3 (E), Q111.3 (E), Q112.3 (E), Q113.3 (E), Q114.3 (E), Q115.3 (E), Q116.3 (E), Q117.3 (E), Q118.3 (E), Q119.3 (E), Q120.3 (E), Q121.3 (E), Q122.3 (E), Q123.3 (E), Q124.3 (E), Q125.3 (E), Q126.3 (E), Q127.3 (E), Q128.3 (E), Q129.3 (E), Q130.3 (E), Q131.3 (E), Q132.3 (E), Q133.3 (E), Q134.3 (E), Q135.3 (E), Q136.3 (E), Q137.3 (E), Q138.3 (E), Q139.3 (E), Q140.3 (E), Q141.3 (E), Q142.3 (E), Q143.3 (E), Q144.3 (E), Q145.3 (E), Q146.3 (E), Q149.3 (E), Q150.3 (E), Q151.3 (E), Q152.3 (E), Q153.3 (E), Q154.3 (E), Q155.3 (E), Q157.3 (E)
unnamed: Q1.2 (B), R1.1
unnamed: Q2.2 (B), R3.1
unnamed: Q3.2 (B), R4.2
unnamed: Q3.1 (C), Q4.1 (C), R5.2, R7.1, R10.1, R28.1
unnamed: Q4.2 (B), R6.2
unnamed: Q5.2 (B), R7.2
unnamed: Q5.1 (C), Q6.1 (C), R8.2, R13.1
unnamed: Q6.2 (B), R9.2
unnamed: Q7.2 (B), R10.2
unnamed: Q7.1 (C), Q8.1 (C), R11.2, R15.1
unnamed: Q8.2 (B), R12.2
unnamed: Q9.2 (B), R13.2
unnamed: Q10.2 (B), R15.2
unnamed: Q9.1 (C), Q10.1 (C), R14.2, R16.1, R19.1
unnamed: Q11.2 (B), R16.2
unnamed: Q11.1 (C), Q12.1 (C), R17.2, R21.1, R22.1, R30.1
unnamed: Q12.2 (B), R18.2
unnamed: Q13.2 (B), R19.2
unnamed: Q13.1 (C), Q14.1 (C), R20.2, R25.1
unnamed: Q14.2 (B), R21.2
unnamed: Q15.2 (B), R22.2
unnamed: Q15.1 (C), Q16.1 (C), R23.2, R27.1
unnamed: Q16.2 (B), R24.2
unnamed: Q17.2 (B), R25.2
unnamed: Q18.2 (B), R27.2
unnamed: Q19.2 (B), R28.2
unnamed: Q20.2 (B), R30.2
unnamed: Q21.2 (B), R31.2
unnamed: Q21.1 (C), Q22.1 (C), R32.2, R34.1, R35.1, R42.1
unnamed: Q22.2 (B), R33.2
unnamed: Q23.2 (B), R34.2
unnamed: Q23.1 (C), Q25.1 (C), R36.2, R40.1
unnamed: Q24.2 (B), R35.2
unnamed: Q24.1 (C), Q26.1 (C), R37.2, R43.1
unnamed: Q25.2 (B), R38.2
unnamed: Q26.2 (B), R39.2
unnamed: Q27.2 (B), R40.2
unnamed: Q27.1 (C), Q29.1 (C), R41.2, R46.1, R49.1
unnamed: Q28.2 (B), R42.2
unnamed: Q29.2 (B), R43.2
unnamed: Q30.2 (B), R45.2
unnamed: Q31.2 (B), R46.2
unnamed: Q31.1 (C), Q32.1 (C), R45.1, R47.2, R50.1, R53.1
unnamed: Q32.2 (B), R48.2
unnamed: Q33.2 (B), R49.2
unnamed: Q33.1 (C), Q35.1 (C), R51.2, R55.1
unnamed: Q34.2 (B), R50.2
unnamed: Q34.1 (C), Q36.1 (C), R52.2, R57.1
unnamed: Q35.2 (B), R53.2
unnamed: Q36.2 (B), R54.2
unnamed: Q37.2 (B), R55.2
unnamed: Q38.2 (B), R57.2
unnamed: Q39.2 (B), R58.2
unnamed: Q39.1 (C), Q40.1 (C), R59.2, R61.1, R62.1, R69.1
unnamed: Q40.2 (B), R60.2
unnamed: Q41.2 (B), R61.2
unnamed: Q41.1 (C), Q43.1 (C), R63.2, R67.1
unnamed: Q42.2 (B), R62.2
unnamed: Q42.1 (C), Q44.1 (C), R64.2, R70.1
unnamed: Q43.2 (B), R65.2
unnamed: Q44.2 (B), R66.2
unnamed: Q45.2 (B), R67.2
unnamed: Q45.1 (C), Q47.1 (C), R68.2, R73.1, R76.1
unnamed: Q46.2 (B), R69.2
unnamed: Q47.2 (B), R70.2
unnamed: Q48.2 (B), R72.2
unnamed: Q49.2 (B), R73.2
unnamed: Q49.1 (C), Q50.1 (C), R72.1, R74.2, R77.1, R80.1
unnamed: Q50.2 (B), R75.2
unnamed: Q51.2 (B), R76.2
unnamed: Q51.1 (C), Q53.1 (C), R78.2, R82.1
unnamed: Q52.2 (B), R77.2
unnamed: Q52.1 (C), Q54.1 (C), R79.2, R84.1
unnamed: Q53.2 (B), R80.2
unnamed: Q54.2 (B), R81.2
unnamed: Q55.2 (B), R82.2
unnamed: Q56.2 (B), R84.2
unnamed: Q57.2 (B), R85.2
unnamed: Q57.1 (C), Q58.1 (C), R86.2, R88.1, R89.1, R96.1
unnamed: Q58.2 (B), R87.2
unnamed: Q59.2 (B), R88.2
unnamed: Q59.1 (C), Q61.1 (C), R90.2, R94.1
unnamed: Q60.2 (B), R89.2
unnamed: Q60.1 (C), Q62.1 (C), R91.2, R97.1
unnamed: Q61.2 (B), R92.2
unnamed: Q62.2 (B), R93.2
unnamed: Q63.2 (B), R94.2
unnamed: Q63.1 (C), Q65.1 (C), R95.2, R100.1, R103.1
unnamed: Q64.2 (B), R96.2
unnamed: Q65.2 (B), R97.2
unnamed: Q66.2 (B), R99.2
unnamed: Q67.2 (B), R100.2
unnamed: Q67.1 (C), Q68.1 (C), R99.1, R101.2, R104.1, R107.1
unnamed: Q68.2 (B), R102.2
unnamed: Q69.2 (B), R103.2
unnamed: Q69.1 (C), Q71.1 (C), R105.2, R109.1
unnamed: Q70.2 (B), R104.2
unnamed: Q70.1 (C), Q72.1 (C), R106.2, R111.1
unnamed: Q71.2 (B), R107.2
unnamed: Q72.2 (B), R108.2
unnamed: Q73.2 (B), R109.2
unnamed: Q74.2 (B), R111.2
unnamed: Q75.2 (B), R112.2
unnamed: Q75.1 (C), Q79.1 (C), R116.2, R124.1, R128.1, R156.1
unnamed: Q76.2 (B), R113.2
unnamed: Q76.1 (C), Q80.1 (C), R117.2, R125.1, R129.1, R157.1
unnamed: Q77.2 (B), R114.2
unnamed: Q77.1 (C), Q81.1 (C), R118.2, R126.1, R130.1, R158.1
unnamed: Q78.2 (B), R115.2
unnamed: Q78.1 (C), Q82.1 (C), R119.2, R127.1, R131.1, R159.1
unnamed: Q79.2 (B), R120.2
unnamed: Q80.2 (B), R121.2
unnamed: Q81.2 (B), R122.2
unnamed: Q82.2 (B), R123.2
unnamed: Q83.2 (B), R124.2
unnamed: Q83.1 (C), Q91.1 (C), R132.2, R148.1
unnamed: Q84.2 (B), R125.2
unnamed: Q84.1 (C), Q92.1 (C), R133.2, R149.1
unnamed: Q85.2 (B), R126.2
unnamed: Q85.1 (C), Q93.1 (C), R134.2, R150.1
unnamed: Q86.2 (B), R127.2
unnamed: Q86.1 (C), Q94.1 (C), R135.2, R151.1
unnamed: Q87.2 (B), R128.2
unnamed: Q87.1 (C), Q95.1 (C), R136.2, R160.1
unnamed: Q88.2 (B), R129.2
unnamed: Q88.1 (C), Q96.1 (C), R137.2, R161.1
unnamed: Q89.2 (B), R130.2
unnamed: Q89.1 (C), Q97.1 (C), R138.2, R162.1
unnamed: Q90.2 (B), R131.2
unnamed: Q90.1 (C), Q98.1 (C), R139.2, R163.1
unnamed: Q91.2 (B), R140.2
unnamed: Q92.2 (B), R141.2
unnamed: Q93.2 (B), R142.2
unnamed: Q94.2 (B), R143.2
unnamed: Q95.2 (B), R144.2
unnamed: Q96.2 (B), R145.2
unnamed: Q97.2 (B), R146.2
unnamed: Q98.2 (B), R147.2
unnamed: Q99.2 (B), R148.2
unnamed: Q100.2 (B), R149.2
unnamed: Q100.1 (C), Q108.1 (C), R153.2, R173.1, R185.1
unnamed: Q101.2 (B), R150.2
unnamed: Q101.1 (C), Q109.1 (C), R154.2, R174.1, R186.1
unnamed: Q102.2 (B), R151.2
unnamed: Q102.1 (C), Q110.1 (C), R155.2, R175.1, R187.1
unnamed: Q103.2 (B), R156.2
unnamed: Q104.2 (B), R157.2
unnamed: Q105.2 (B), R158.2
unnamed: Q106.2 (B), R159.2
unnamed: Q107.2 (B), R160.2
unnamed: Q99.1 (C), Q107.1 (C), R152.2, R172.1, R184.1
unnamed: Q108.2 (B), R161.2
unnamed: Q109.2 (B), R162.2
unnamed: Q110.2 (B), R163.2
unnamed: Q111.2 (B), R168.2
unnamed: Q112.2 (B), R169.2
unnamed: Q113.2 (B), R170.2
unnamed: Q114.2 (B), R171.2
unnamed: Q115.2 (B), R172.2
unnamed: Q115.1 (C), Q119.1 (C), R168.1, R176.2, R188.1, R200.1
unnamed: Q116.2 (B), R173.2
unnamed: Q116.1 (C), Q120.1 (C), R169.1, R177.2, R189.1, R201.1
unnamed: Q117.2 (B), R174.2
unnamed: Q117.1 (C), Q121.1 (C), R170.1, R178.2, R190.1, R202.1
unnamed: Q118.2 (B), R175.2
unnamed: Q118.1 (C), Q122.1 (C), R171.1, R179.2, R191.1, R203.1
unnamed: Q119.2 (B), R180.2
unnamed: Q120.2 (B), R181.2
unnamed: Q121.2 (B), R182.2
unnamed: Q122.2 (B), R183.2
unnamed: Q123.2 (B), R184.2
unnamed: Q123.1 (C), Q131.1 (C), R192.2, R208.1
unnamed: Q124.2 (B), R185.2
unnamed: Q124.1 (C), Q132.1 (C), R193.2, R209.1
unnamed: Q125.2 (B), R186.2
unnamed: Q125.1 (C), Q133.1 (C), R194.2, R210.1
unnamed: Q126.2 (B), R187.2
unnamed: Q126.1 (C), Q134.1 (C), R195.2, R211.1
unnamed: Q127.2 (B), R188.2
unnamed: Q127.1 (C), Q135.1 (C), R196.2, R216.1
unnamed: Q128.2 (B), R189.2
unnamed: Q128.1 (C), Q136.1 (C), R197.2, R217.1
unnamed: Q129.2 (B), R190.2
unnamed: Q129.1 (C), Q137.1 (C), R198.2, R218.1
unnamed: Q130.2 (B), R191.2
unnamed: Q130.1 (C), Q138.1 (C), R199.2, R219.1
unnamed: Q131.2 (B), R200.2
unnamed: Q132.2 (B), R201.2
unnamed: Q133.2 (B), R202.2
unnamed: Q134.2 (B), R203.2
unnamed: Q135.2 (B), R204.2
unnamed: Q136.2 (B), R205.2
unnamed: Q137.2 (B), R206.2
unnamed: Q138.2 (B), R207.2
unnamed: Q139.2 (B), R208.2
unnamed: Q140.2 (B), R209.2
unnamed: Q141.2 (B), R210.2
unnamed: Q142.2 (B), R211.2
unnamed: Q143.2 (B), R216.2
unnamed: Q144.2 (B), R217.2
unnamed: Q145.2 (B), R218.2
unnamed: Q146.2 (B), R219.2
unnamed: Q149.2 (B), R224.1
unnamed: Q150.2 (B), R226.1
unnamed: Q151.2 (B), R227.1
unnamed: Q152.2 (B), R230.1
unnamed: Q153.2 (B), R231.1
unnamed: Q154.2 (B), R232.1
unnamed: Q155.2 (B), R233.1
unnamed: Q156.2 (B), R239.1
unnamed: Q156.3 (E), Q157.1 (C)
unnamed: Q157.2 (B), R240.1
Out_Bit0: J1.21, Q17.1 (C), Q18.1 (C), R26.2
Out_Bit1: J1.22, Q37.1 (C), Q38.1 (C), R56.2
Out_Bit2: J1.23, Q55.1 (C), Q56.1 (C), R83.2
Out_Bit3: J1.24, Q73.1 (C), Q74.1 (C), R110.2
Out_Bit4: J1.25, Q139.1 (C), Q143.1 (C), R212.2
Out_Bit5: J1.26, Q140.1 (C), Q144.1 (C), R213.2
Out_Bit6: J1.27, Q141.1 (C), Q145.1 (C), R214.2
Out_Bit7: J1.28, Q142.1 (C), Q146.1 (C), R215.2
UseCarryFlag: J1.20, R240.2

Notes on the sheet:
Add Bit2
Add Bit1
Add Bit5
Carry Flag = !Borrow7
Add Bit0
Add Bit3
Add Bit4
Add Bit6
Carry out (For flag)
CarryFlag NAND UseCarryFlag Makes the borrow in 1 if not using carry (b/c of 2's complement) Else makes the borrow in !CarryFlag if we are using carry
Add Bit7
Invert B for 2's Complement



Board: 2 copper layers, 90.0 x 99.9 mm, 393 parts (238 on the bottom side), 258 nets.

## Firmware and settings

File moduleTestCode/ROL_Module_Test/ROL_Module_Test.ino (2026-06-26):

#define carryFlagPin 0
#define throughCarryFlagPin 1
#define outCarryFlagPin 18
#define ABit0Pin 2
#define ABit7Pin 9
#define OutBit0Pin 10
#define OutBit7Pin 17

void setup() {
  // put your setup code here, to run once:
  Serial.begin(115200); 
  while(!Serial){;}

  for(int i=ABit0Pin; i<=ABit7Pin; i++){
    pinMode(i, OUTPUT);
  }
  pinMode(carryFlagPin, OUTPUT);
  pinMode(throughCarryFlagPin, OUTPUT);

  for(int i=OutBit0Pin; i<=OutBit7Pin; i++){
    pinMode(i, INPUT);
  }
  pinMode(outCarryFlagPin, INPUT);
}

int testNumber = 0;
int testMode = 0;

void loop() {

  if(testMode > 3) {
    Serial.println("ALL TESTS COMPLETE");
    while(true){}
  }

  bool carryIn;
  bool throughCarry;

  switch(testMode) {
    case 0: // RRC
      carryIn = 0;
      throughCarry = 0;
      break;

    case 1: // RRC with carry=1
      carryIn = 1;
      throughCarry = 0;
      break;

    case 2: // RAR carry=0
      carryIn = 0;
      throughCarry = 1;
      break;

    case 3: // RAR carry=1
      carryIn = 1;
      throughCarry = 1;
      break;
  }

  writeA(testNumber);

  digitalWrite(carryFlagPin, carryIn ? HIGH : LOW);
  digitalWrite(throughCarryFlagPin, throughCarry ? HIGH : LOW);

  delay(1);

  int actual = readResult();
  int actualCarry = digitalRead(outCarryFlagPin);

  int expected;
  int expectedCarry = testNumber & 1;

  if(throughCarry) {
    // RAR
    expected = (testNumber >> 1) | (carryIn ? 0x80 : 0x00);
  } else {
    // RRC
    expected = (testNumber >> 1) | (expectedCarry ? 0x80 : 0x00);
  }

  bool pass =
    (actual == expected) &&
    (actualCarry == expectedCarry);

  Serial.print(pass ? "PASS " : "FAIL ");

  Serial.print("Mode=");
  Serial.print(testMode);

  Serial.print(" A=");
  print8(testNumber);

  Serial.print(" Result=");
  print8(actual);

  Serial.print(" Expected=");
  print8(expected);

  Serial.print(" Carry=");
  Serial.print(actualCarry);

  Serial.print(" ExpectedCarry=");
  Serial.println(expectedCarry);

  testNumber++;

  if(testNumber > 0xFF) {
    testNumber = 0;
    testMode++;

    Serial.println();
    Serial.println("====================================");
    Serial.print("STARTING MODE ");
    Serial.println(testMode);
    Serial.println("====================================");
    Serial.println();
  }
}

void print8(uint8_t value) {
  for(int i = 7; i >= 0; i--) {
    Serial.print((value >> i) & 1);
  }
}

void writeA(int num){
  for(int i=ABit0Pin; i<=ABit7Pin; i++){
    int digit = num & 0b1;
    digitalWrite(i, digit == 1 ? HIGH : LOW);
    num >>= 1;
  }
}

int readResult(){
  int out = 0;
  for(int i=OutBit7Pin; i>=OutBit0Pin; i--){
    out <<= 1;
    out |= digitalRead(i)==HIGH ? 1 : 0;
  }
  return out;
}

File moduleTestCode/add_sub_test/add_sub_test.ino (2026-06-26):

int aPins[] = {0, 1, 2, 3, 4, 5, 6, 7}; 
int bPins[] = {8, 9, 10, 11, 12, 13, 14, 15}; 
int outPins[] = {16, 17, 18, 19, 20, 21, 22, 26}; 

int carryFlagPin = 27;
int carryFlagOutPin = 28;

void setup() {
  // put your setup code here, to run once:
  Serial.begin(115200); 
  while(!Serial){;}

  for(int i=0; i<8; i++){
    pinMode(aPins[i], OUTPUT);
    pinMode(bPins[i], OUTPUT);
  }
  pinMode(carryFlagPin, OUTPUT);

  for(int i=0; i<8; i++){
    pinMode(outPins[i], INPUT);
  }
  pinMode(carryFlagOutPin, INPUT);
}

bool useCarryFlag = false;
int borrow = 0;

int a = 0b00000000;
int b = 0b00000000;
int fails = 0;

void loop() {
  if(b > 0xFF){ return; }

  digitalWrite(carryFlagPin, borrow==1 ? HIGH : LOW);

  writeInput(a, aPins);
  writeInput(b, bPins);
  delay(1);
  int r = readResult();
  int cf = digitalRead(carryFlagOutPin)==HIGH ? 1 : 0;

  int operation = a - b - borrow;
  int expected = operation & 0xFF;
  //int expectedCarryOut = (operation & 0x100) >> 8; // the 9th bit, for ADD
  int expectedCarryOut = (a < (b + borrow)) ? 1 : 0; // for SUB, check if a is less than b

  bool pass = (r == expected);
  if(useCarryFlag) { pass &= (cf == expectedCarryOut); }

  Serial.print( pass ? "PASS" : "FAIL" );
  Serial.print(" | A: ");
  print8(a);
  Serial.print(", B: ");
  print8(b);
  Serial.print(" ; Out: ");
  print8(r);
  Serial.print(" ~ Carry out: ");
  Serial.print(cf);
  Serial.print(", Expected: ");
  print8(expected);
  Serial.print(" ~ Carry out: ");
  Serial.print(expectedCarryOut);
  Serial.println("");

  if( !pass ){ fails++; return; }
  //return;

  a++;
  if(a > 0xFF){
    a = 0x00;
    b++;
  }
  if( b > 0xFF ){
    Serial.print("Testing done! Total fails: ");
    Serial.println(fails);
  }
}

void print8(uint8_t value) {
  for(int i = 7; i >= 0; i--) {
    Serial.print((value >> i) & 1);
  }
}

void writeInput(int num, int pins[]){
  for(int i=0; i<8; i++){
    int digit = num & 0b1;
    digitalWrite(pins[i], digit == 1 ? HIGH : LOW);
    num >>= 1;
  }
}

int readResult(){
  int out = 0;
  for(int i=7; i>=0; i--){
    out <<= 1;
    out |= digitalRead(outPins[i])==HIGH ? 1 : 0;
  }
  return out;
}

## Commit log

2026-04-25 Created the ADD schematic and placed the components on the PCB, need to do routing still
    [FullAdder_8Bit.kicad_pcb, FullAdder_8Bit.kicad_sch]
2026-04-25 Did some routing!
    [FullAdder_8Bit.kicad_pcb, FullAdder_8Bit.kicad_sch]
2026-04-25 some kicad files locked removed
2026-04-26 Finished the ADD PCB
    [FullAdder_8Bit.kicad_pcb, FullAdder_8Bit.kicad_sch]
2026-04-26 Made a backup; removed all traces and put parts where they need to be. starting routing again
    [FullAdder_8Bit.kicad_sch]
2026-04-27 Revert "Made a backup; removed all traces and put parts where they need to be. starting routing again"
    This reverts commit 2ef9f42e64e6a7f49d503f8bd060bf19175d52bc.
    [FullAdder_8Bit.kicad_sch]
2026-04-27 Started making the subtractor
    [FullSubtractor_8Bit.kicad_pcb, FullSubtractor_8Bit.kicad_sch]
2026-04-27 8 Bit Subtractor Done!
    [FullSubtractor_8Bit.kicad_pcb]
2026-04-27 Bitwise AND Module fully complete
    [LogicalAND_8Bit.kicad_pcb, LogicalAND_8Bit.kicad_sch]
2026-04-27 Bitwise OR is fully done; Plus i remembered to cross it out on the doc
    [LogicalOR_8Bit.kicad_pcb, LogicalOR_8Bit.kicad_sch]
2026-04-28 Finished the XOR module and added silk screens to OR, AND, and XOR
    [LogicalAND_8Bit.kicad_pcb, LogicalOR_8Bit.kicad_pcb, LogicalXOR_8Bit.kicad_pcb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]
2026-04-28 DAA > 0x9 detector circuit in falstad
2026-04-28 Bitwise NOT module complete
    [LogicalNOT_8Bit.kicad_pcb, LogicalNOT_8Bit.kicad_sch]
2026-04-28 Finished Rotate Left and Rotate Right w/ through carry flag
    [RotateLeft_8Bit.kicad_pcb, RotateLeft_8Bit.kicad_sch, RotateRight_8Bit.kicad_pcb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]
2026-04-29 created the bom and updated the readme
2026-04-29 Generated fab files for all of the pcbs + a backup from kicad ig
    [bom.csv, designators.csv, positions.csv]
2026-04-29 Added PCB Csot, and images to the readme
